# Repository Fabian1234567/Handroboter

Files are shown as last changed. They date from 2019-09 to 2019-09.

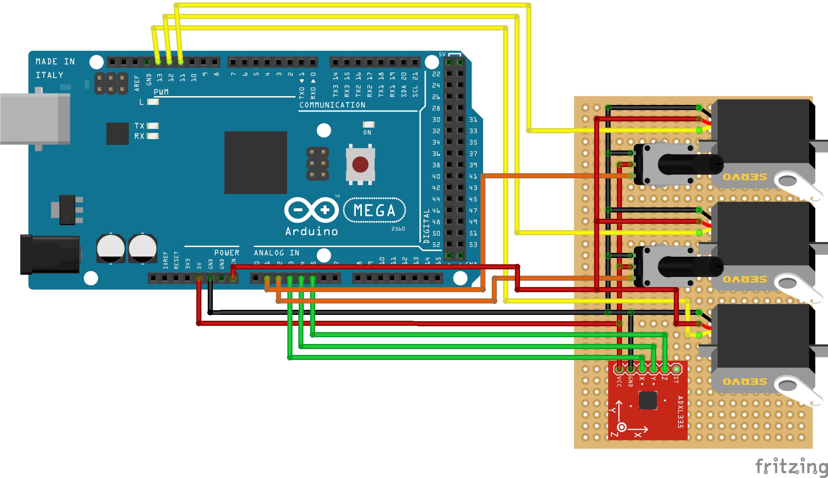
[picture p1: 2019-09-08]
Konstruktionen/BauplanRoboter_Schaltplan.jpg

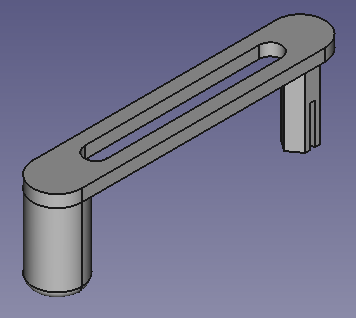
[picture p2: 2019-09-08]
Konstruktionen/Poti.png

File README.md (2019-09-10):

# Handroboter

SIA (Schüler-Ingenieurs-Akademie) ist ein Schulfach in Baden-Würrtemberg, wo man Roboter und andere Maschinen mit Microkontroller baut. Das Fach wird in der 11. Klasse an einzelnen Schulen angeboten und kann als mündliches Abitur gezählt werden. 

Mein Projektziel:  Bau eines Roboterarms, dessen Steuerung durch die menschlichen Hand-Bewegungen mittels eines mit Sensoren versehenen Handschuhs erfolgt. Die Sensorsignale werden von einem Mikrocomputer (Arduino) verarbeitet, der damit die Stellmotoren des Roboterarmes steuert. Wenn möglich soll der Roboterarm gezielt kleine Gegenstände bewegen und heben können.
- Das Projektziel wurde erreicht.

Normalerweise arbeitet man in Teams, doch mich hat man aufgrund meines Vorwissens in eine Einzelgruppe gesetzt. Als Microkontroller haben wir Arduino Megas genutzt. Meine Dokumentation, Werkstatttagbeücher, Konstruktion, Präsentation und Programm findet man hier. Vielleicht hilft es euch, ein ähnliches Projekt umzusetzen :) .

Meine Noten im Fach: 
- Gesamtbewertung: 14p
- incl. Jahresleistung: 14p
- u. Dokumentation: 11p
- u. Kolloquien: 15p

Ich wünsche euch viel Spaß mit diesem Projekt!
- If you have any questions please contact me at fabian.exel@gmx.de -

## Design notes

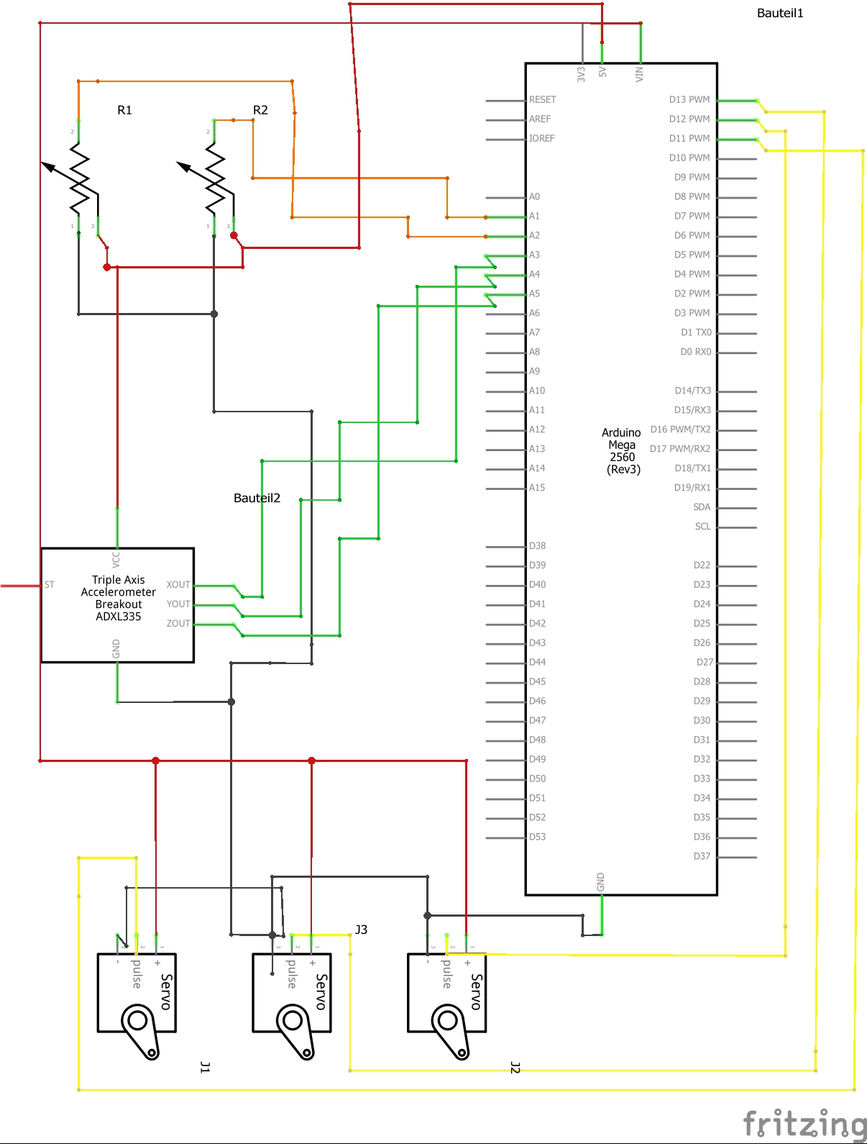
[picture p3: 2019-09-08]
Konstruktionen/BauplanRoboter_Steckplatine.jpg

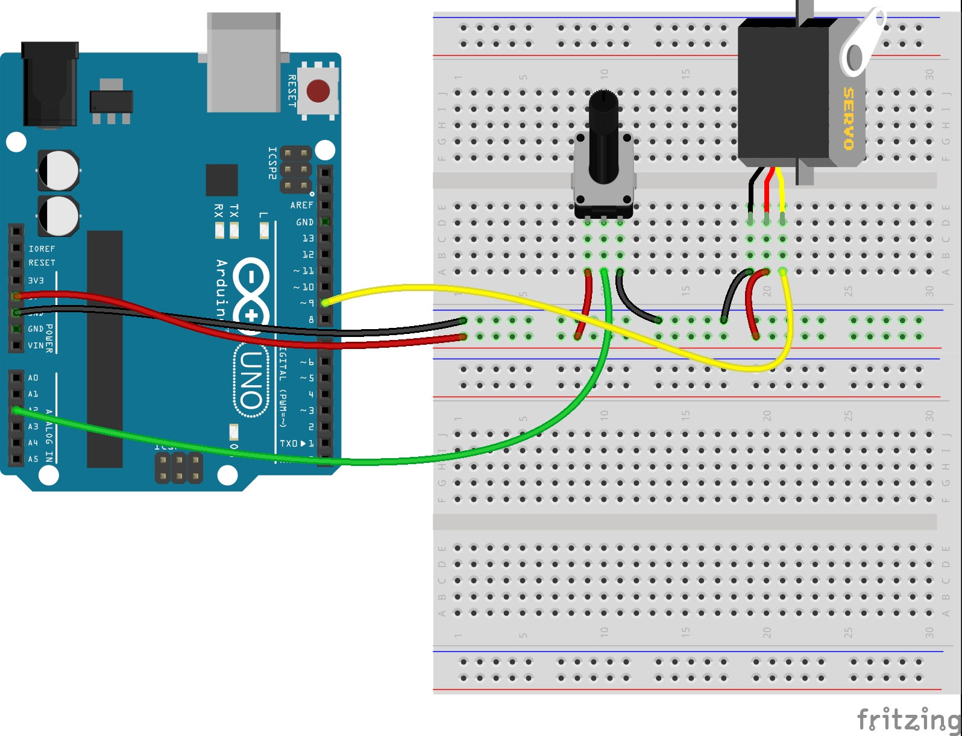
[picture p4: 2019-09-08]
Konstruktionen/AnalogInputToServo_Steckplatine.jpg

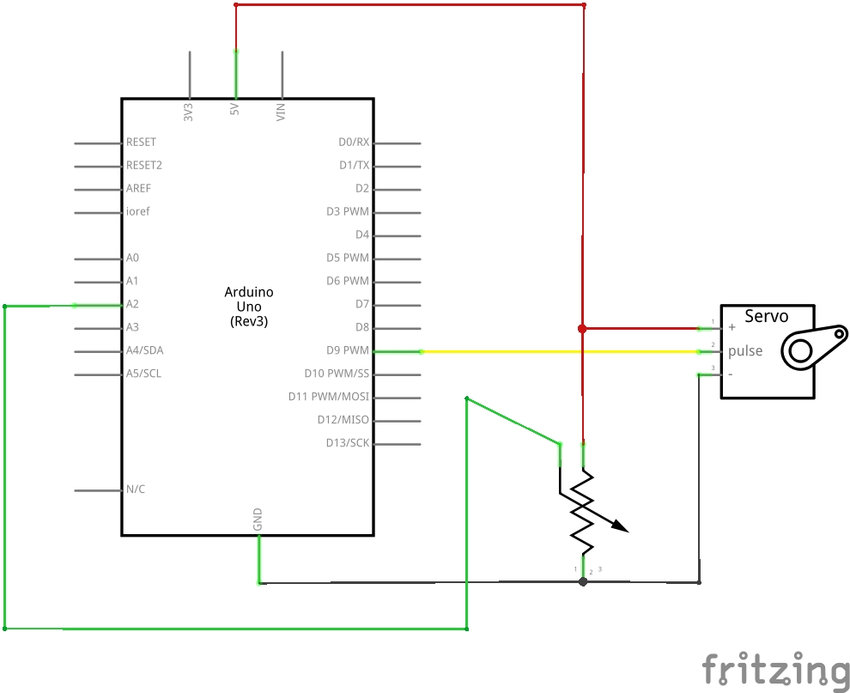
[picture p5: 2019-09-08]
Konstruktionen/AnalogInputToServo_Schaltplan.jpg

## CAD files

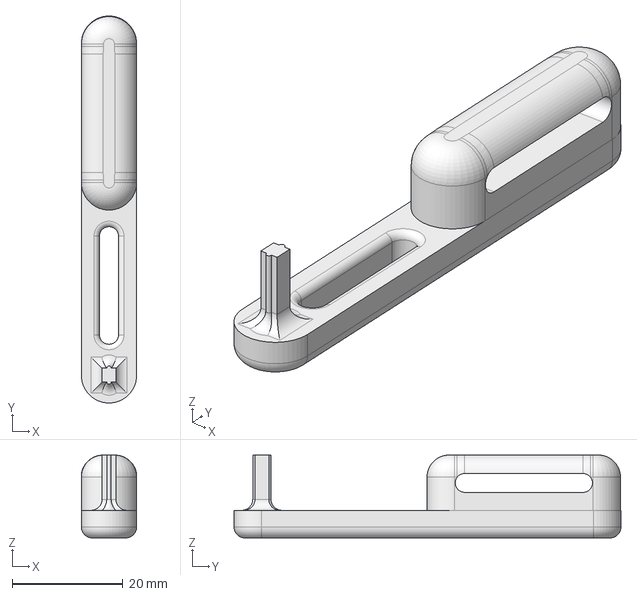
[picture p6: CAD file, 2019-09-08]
Konstruktionen/Poti2KurzÜberarbeitet.FCStd
10.0 x 70.0 x 15.0 mm

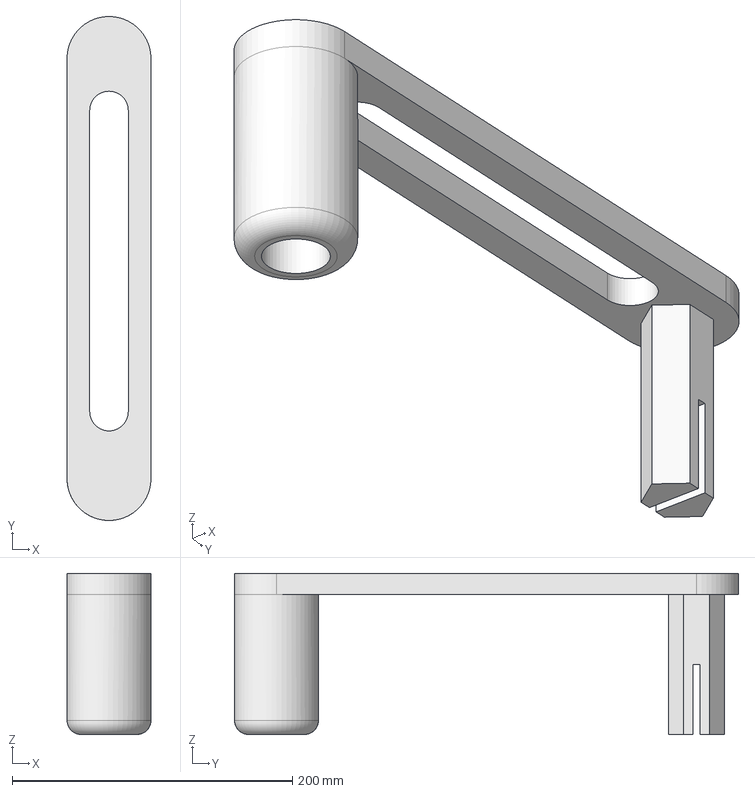
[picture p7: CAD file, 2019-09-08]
Konstruktionen/Poti.fcstd
60.0 x 360.0 x 115.0 mm

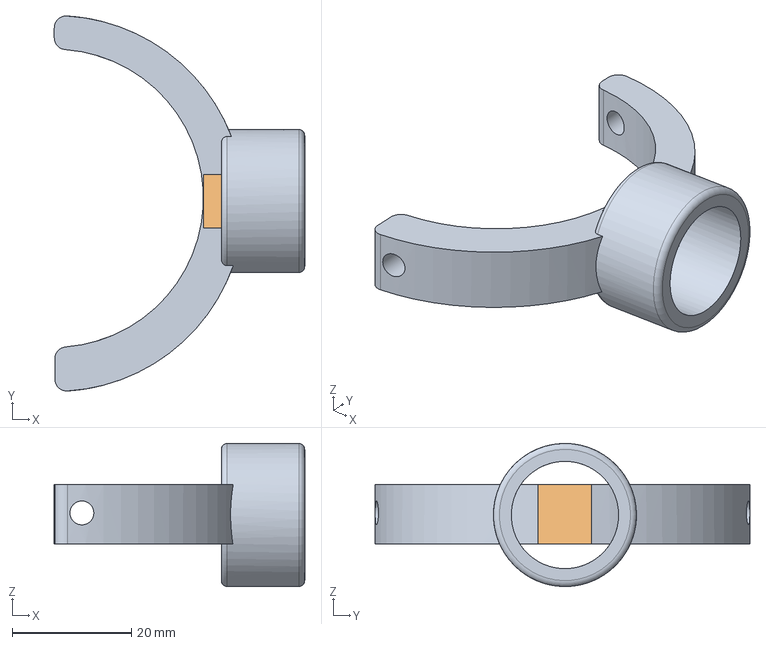
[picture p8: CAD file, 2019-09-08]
Konstruktionen/Hand.FCStd
42.0 x 62.9 x 24.0 mm
Würfel001

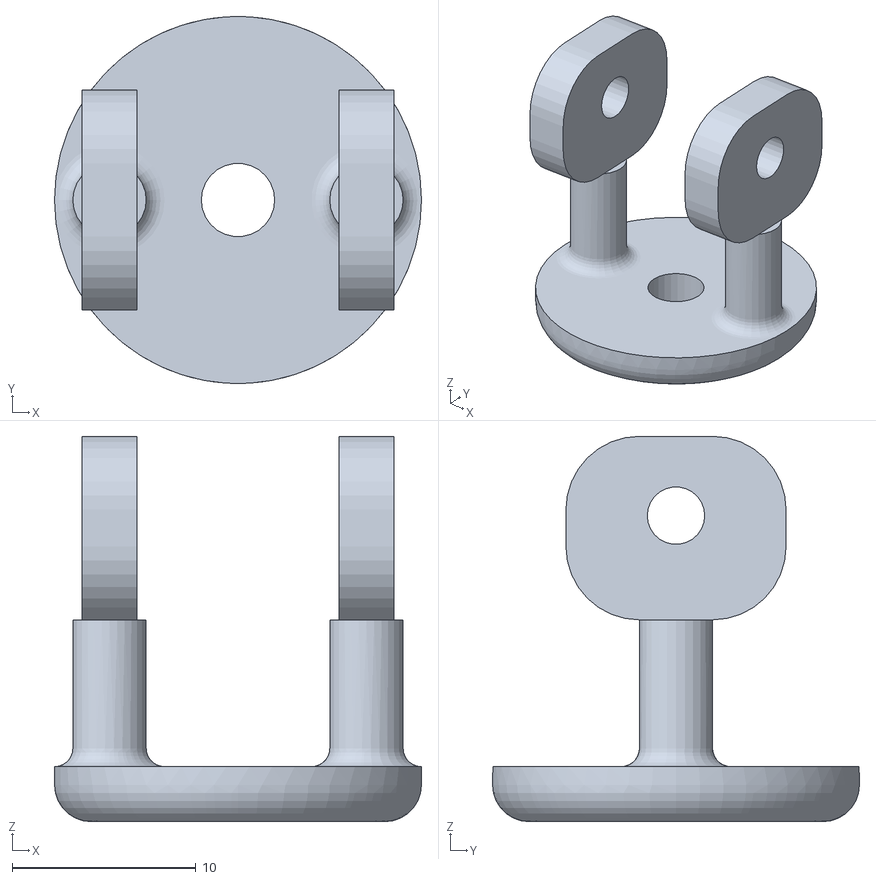
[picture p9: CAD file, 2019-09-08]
Konstruktionen/Poti-Hand-Dreh.stl
20.0 x 20.0 x 21.0

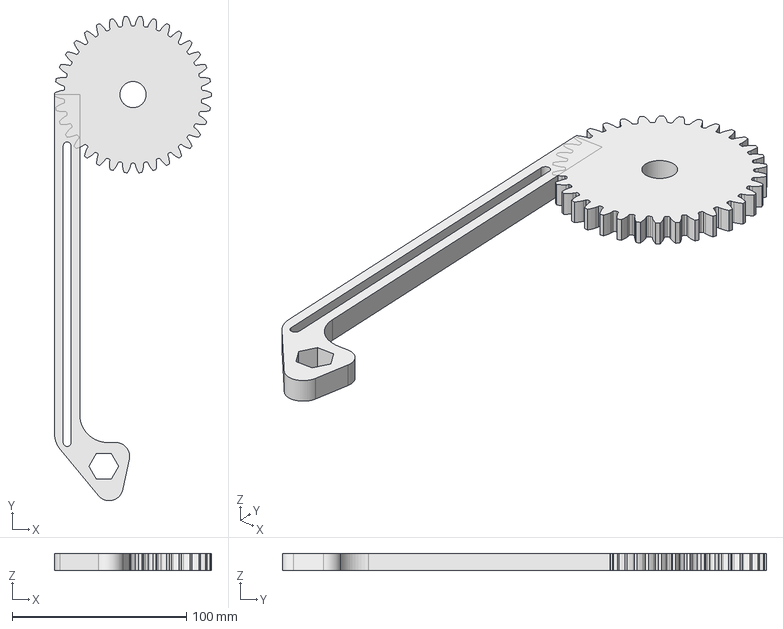
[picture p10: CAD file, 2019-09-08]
Konstruktionen/ZahnradGreifer.FCStd
90.0 x 277.8 x 10.0 mm

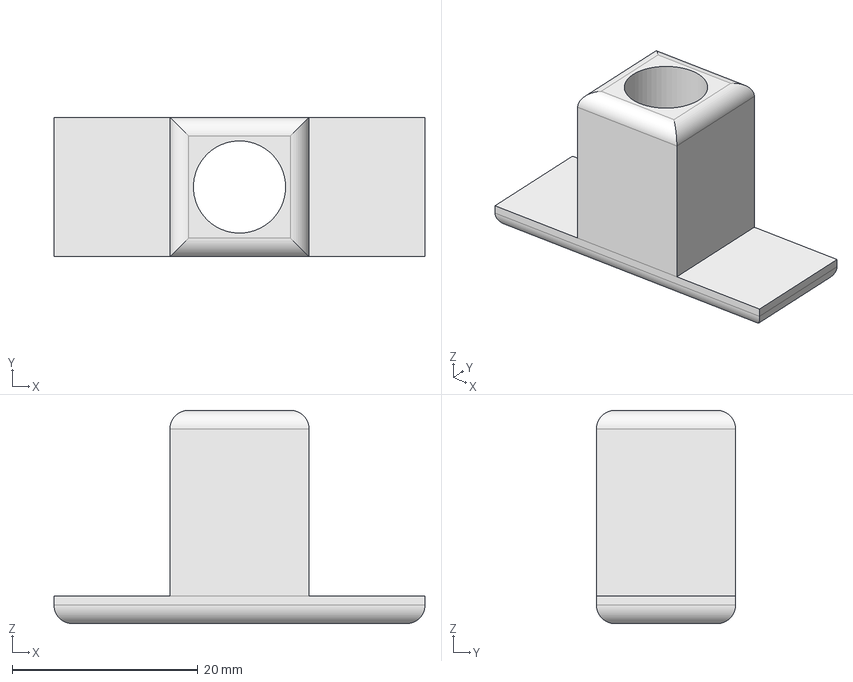
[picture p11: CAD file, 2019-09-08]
Konstruktionen/Stift.FCStd
40.0 x 15.0 x 23.0 mm

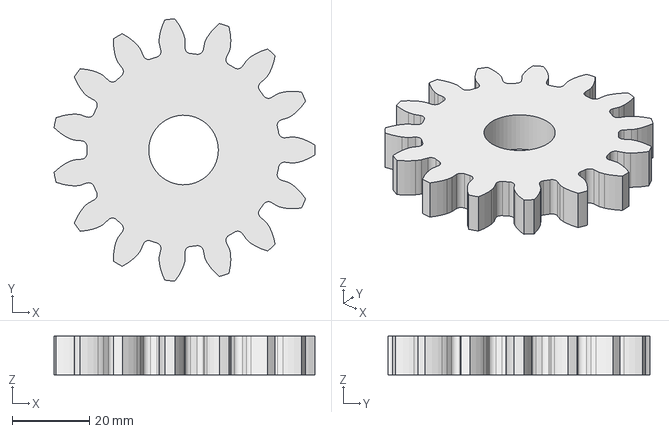
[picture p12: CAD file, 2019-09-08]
Konstruktionen/ZahnradAmServo.FCStd
67.5 x 67.9 x 10.0 mm

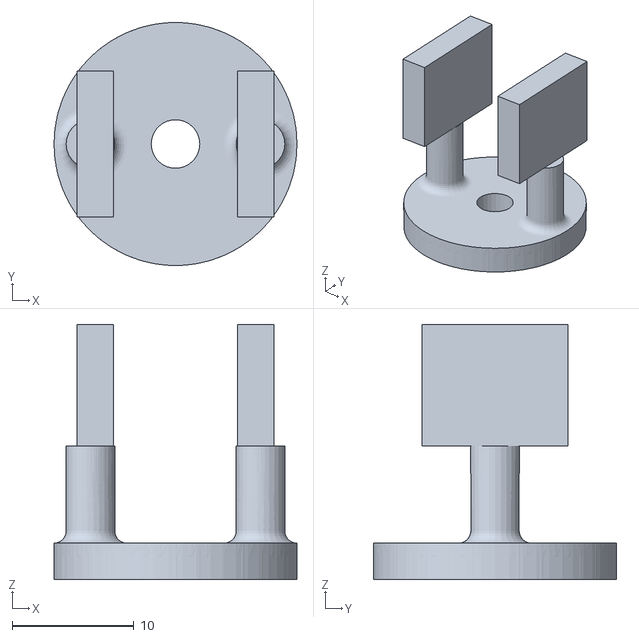
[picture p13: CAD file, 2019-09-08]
Konstruktionen/DrehTeil.stl
20.0 x 20.0 x 21.0

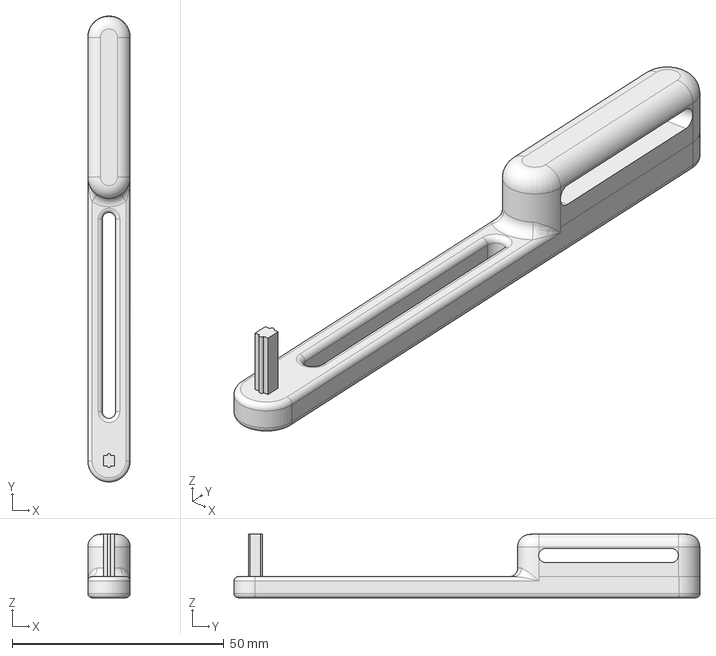
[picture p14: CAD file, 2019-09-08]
Konstruktionen/Poti2.FCStd
10.0 x 110.0 x 15.0 mm

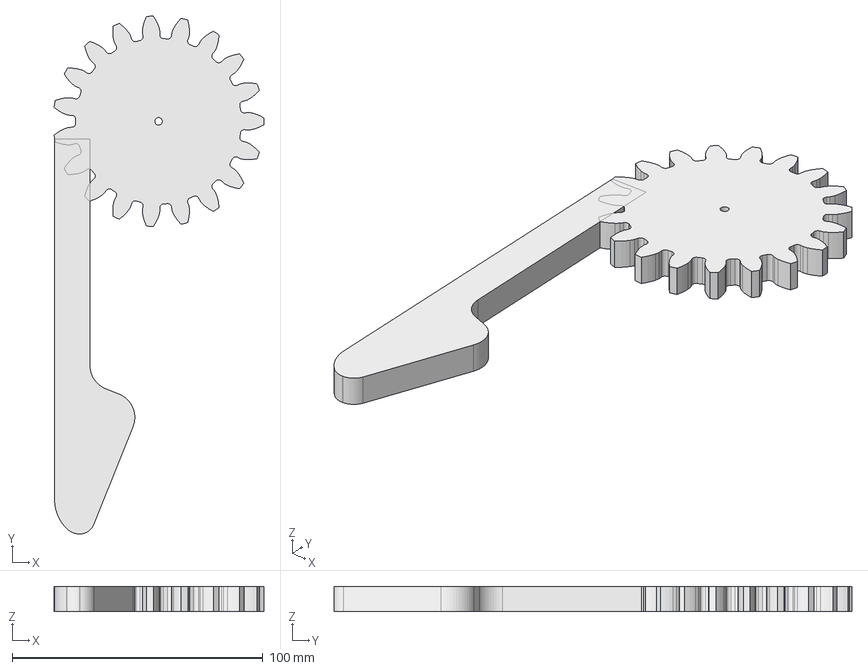
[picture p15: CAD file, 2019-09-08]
Konstruktionen/ZahnradGreifer2.FCStd
83.6 x 206.4 x 10.0 mm

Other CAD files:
Konstruktionen/Poti2Kurz.FCStd
Konstruktionen/Poti-Handschuh.stl
Konstruktionen/richtigesDrehteil.stl
Konstruktionen/Dreh.FCStd
Konstruktionen/Hand.stl
Konstruktionen/Poti2.stl
Konstruktionen/Poti2Kurz.stl
Konstruktionen/Poti2KurzÜberarbeitet.stl
Konstruktionen/Stift.stl
Konstruktionen/ZahnradAmServo.stl
Konstruktionen/ZahnradGreifer.stl

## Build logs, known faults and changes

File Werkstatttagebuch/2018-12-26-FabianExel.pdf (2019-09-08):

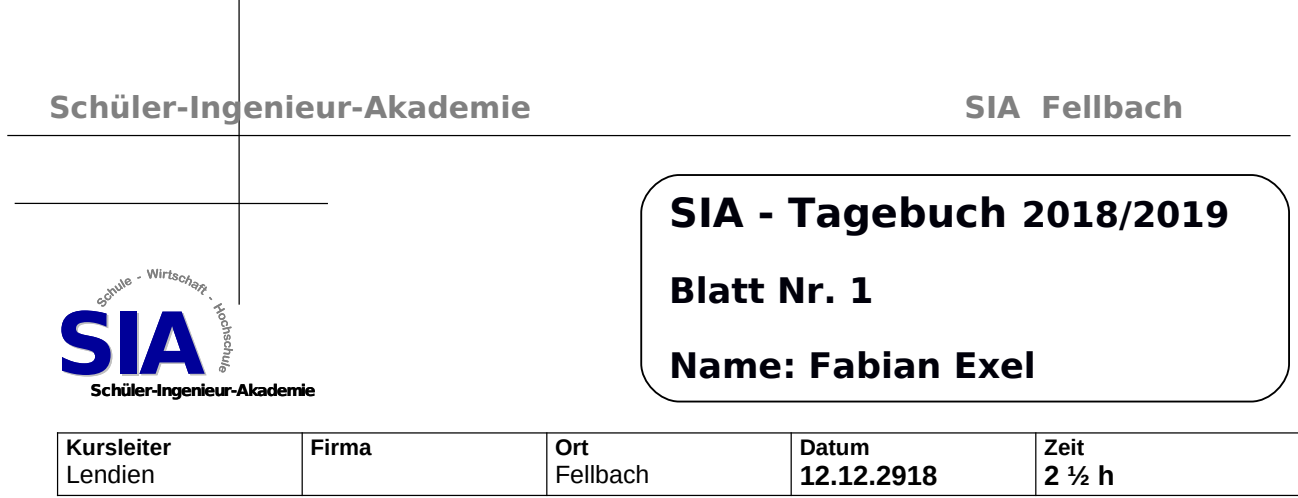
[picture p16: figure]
Schüler-Ingenieur-Akademie; SIA Fellbach; SIA; Schüler Schüler-Ingenieur Ingenieur-Akademie Akademie; Kursleiter Lendien; Firma; Ort; Fellbach; Datum 12.12.2918; Zeit 2 ½ h; SIA - Tagebuch 2018/2019; Blatt Nr. 1; Name: Fabian Exel

### Thema

## Programmierung von Sensor + Motoren Konstruktion

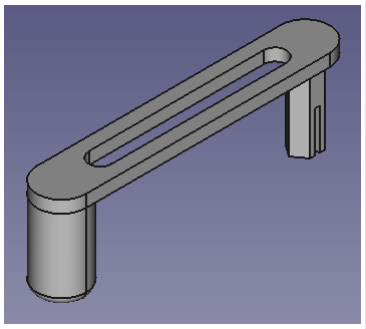
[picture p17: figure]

Was wurde gemacht?

Es wurde für die Hand ein Verbindungsstück zischen einem Potentiometer und dem Finger konstruiert. Man braucht dieses Verbindungsstück, damit man Werte mit dem Potentiometer aufnehmen kann. Als anderen Sensor könnte man noch Neigungssensoren nutzen, nur dann würde es mit der Programmierung und dem Kabelsalat viel schwieriger werden, weil man die Neigungssensoren untereinander abstimmen muss (wenn man mehrere nutzt) und man pro Neigungssensor 5 Kabel hat anstatt 3 Kabel wie bei einen Potentiometer. Das Verbindungsstück muss mindestens zwei mal ausgedruckt werden, weil 2 Potentiometer eingebaut werden sollen (siehe Tagebucheinträge von davor). Später wurde noch mit dem Arduino-Programm angefangen (siehe Seiten danach). Mir ist es dabei wichtig gewesen, dass der Arduino alle seine Werte in einer Seriellen Konsole anzeigt, damit ich weiß, wie ich die Werte verändern muss, damit der Roboter keine komischen Bewegungen macht. Eventuell werden noch ein paar Befehle programmiert, womit man das Programm auch laufend modifizieren kann. Ganz wichtig ist aber die Hand zu testen, bevor sie mit dem Roboter verbunden wird. Dies kann durch eine Simulation zum Beispiel geschehen. Eine andere Sache, die ich auch sehr wichtig finde, ist die Frage, was passiert wenn man seine (echte) Hand in einer Bewegung bewegt, wo sich der Neigungssensor auf einer bestimmten Achse nicht bewegen soll.
In der Regel wird er veränderte Werte aufnehmen, weil die
wenigsten Menschen es schaffen werden, ihre Hand so perfekt zu

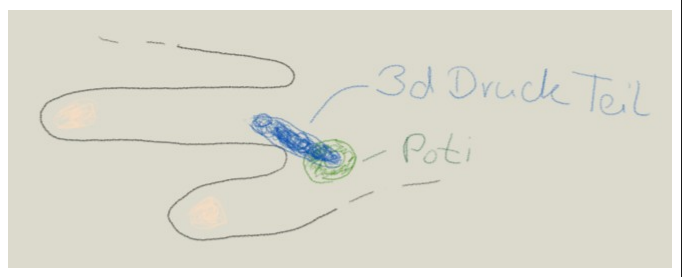
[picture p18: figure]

bewegen, dass kein veränderter Wert auf dieser Achse zu messen ist. Um dieses Problem zu umgehen habe ich eine gewisse Toleranz mit rein programmiert, damit so etwas nicht passiert.

Was wir nächste Stunde voraussichtlich geschehen?

Der Roboterarm wird angefangen zu bauen, die Bauteile sind ja schon alle vorhanden. Die Holzplatte mit dem Ständer werden bei mir Zuhause schon vorgefertigt, damit ich mich nächster Stunde damit nicht aufhalten muss. Des weiteren wird noch Pappelholz mitgenommen zur Weiterverarbeitung beim Roboterarm.

Arbeitsblätter:

Schaubild 1: Verbindungsstück zwischen Potentiometer und Finger

Schaubild 2: Wie das Verbindungsstück eingebaut werden

Arduino Sketch Version 1

#include <Servo.h>

int accZPin=0;
int accYPin=1;
int accXPin=2;
int onePot=3;
int twoPot=4;

int eins;
int zwei;
int drei;

int start;
int abweichung=30;
int neu;

Servo first;
Servo second;
Servo third;

void setup() {
// put your setup code here, to run once: Serial.begin(9600);
first.attach(10);
second.attach(11);
third.attach(12);
start=analogRead(accZPin);
}

void loop() {
// put your main code here, to run repeatedly: Serial.print(" X=");
Serial.print(analogRead(accXPin)); Serial.print(" Y=");
Serial.print(analogRead(accYPin)); Serial.print(" Z=");
Serial.println(analogRead(accZPin)); eins = analogRead(onePot);
eins = map(eins, 0, 1023, 30, 300); Serial.print(" Potentiometer 1: "); Serial.print(onePot);
zwei = analogRead(twoPot);
zwei = map(zwei, 0, 1023, 30, 300); Serial.print(" Potentiometer 2: "); Serial.println(twoPot);
first.write(eins);
Serial.print(" Servo 1: "); Serial.print(eins);
second.write(zwei);
Serial.print(" Servo 2: "); Serial.println(zwei);
if(analogRead(accZPin)>start+abweichung){ neu=analogRead(accZPin)+start; start=neu;
drei=map(drei, 0, 1023, 20, 310); third.write(drei);

}

if(analogRead(accZPin)<start-abweichung){ neu=analogRead(accZPin)-start; start=neu;
drei=map(neu, 0, 1023, 20, 310); third.write(drei);
}
Serial.print(" start-Wert für Neigungssensor: "); Serial.print(start);
Serial.print(" Neuer Wert: "); Serial.print(neu);
Serial.print(" Servo 3: "); Serial.println(drei);
}

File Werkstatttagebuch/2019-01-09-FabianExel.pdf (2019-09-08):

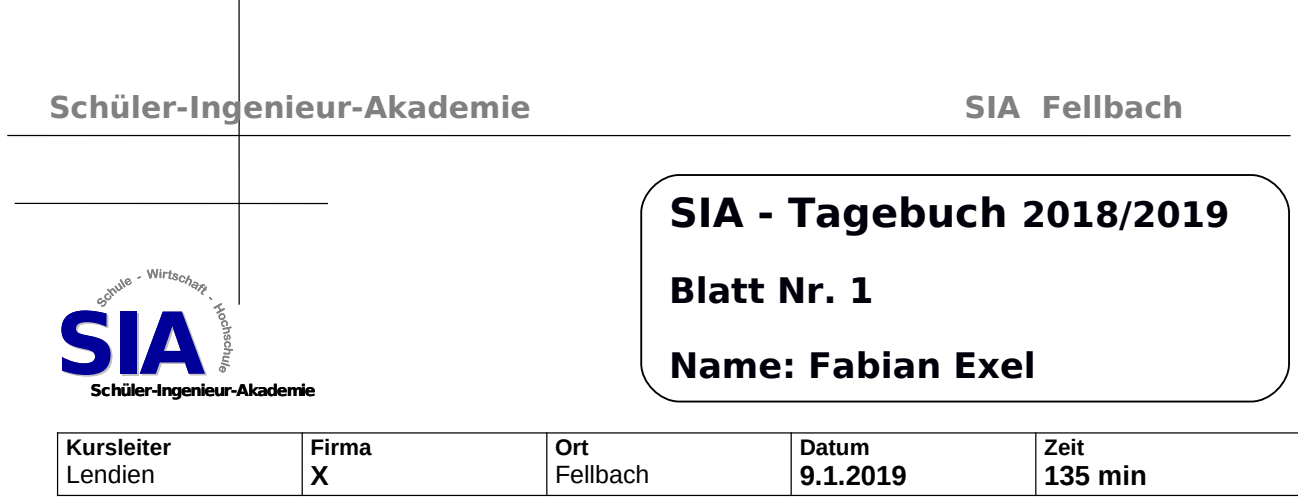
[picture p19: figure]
Schüler-Ingenieur-Akademie; SIA Fellbach; SIA; Schüler Schüler-Ingenieur Ingenieur-Akademie Akademie; Kursleiter Lendien; Firma X; Ort Fellbach; Datum 9.1.2019; Zeit 135 min; SIA - Tagebuch 2018/2019; Blatt Nr. 1; Name: Fabian Exel

### Thema

## Anfang vom Bau des Roboters

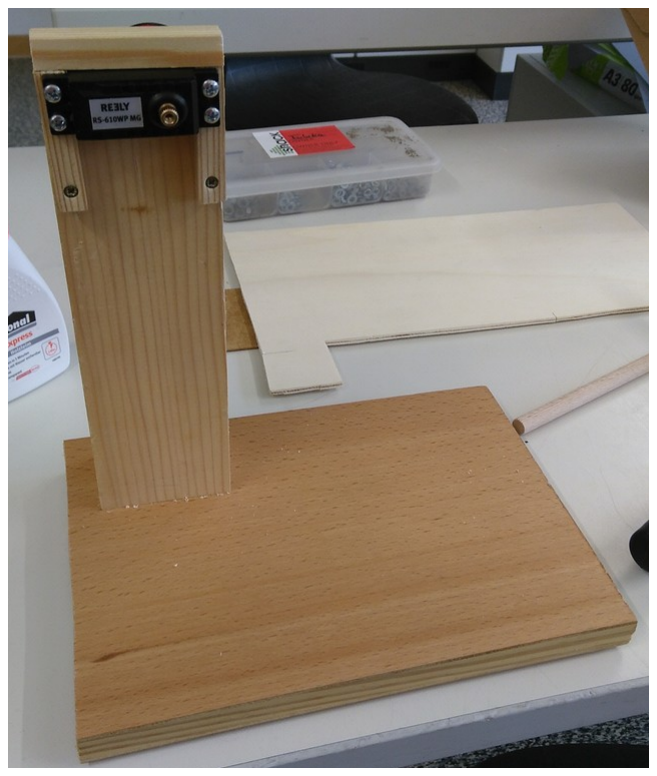
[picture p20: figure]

Was wurde gemacht?
Wie angekündigt wurde schon die Grundplatte mit der Säule bei mir Zuhause vorgefertigt, um Zeit zu sparen. Heute konnte somit direkt mit der Montage der Servos begonnen werden. Mir war wichtig, dass der am stärksten belastete Servo auch der stärkste ist, damit dieser nicht direkt aufgrund zu hoher Kraft in die Knie geht. Außerdem wurde der erste Servo direkt mit 4 Schrauben (2 je Seite – siehe Bild) montiert, damit dieser auch stabil an seinem Platz bleibt und nicht sich losbricht durch äußere Krafteinwirkung.
Später wurde noch der 2. Servo montiert. Dies stellte anfangs eine gewisse Schwierigkeit da, weil es noch unklar war, wie man ihn an den 1. Servo überhaupt montiert. Die erste Idee war, dass man ein Holzstück nimmt, ein großes Loch bohrt und dieses dann auf den Servoanschluss drüber steckt. Dies hat nicht funktioniert, da dieses Holzstück nie fest genug am Servo war und sich andauernd gelöst hat. Zum Glück ist mir aber dann ein Gewinde an dem Servoanschluss, welches auch rein zufällig M3 war – genauso wie meine Schrauben. Damit war klar, dass man für eine stabile Verbindung einfach ein Stück Holz mit der Schraube richtig fest schrauben muss – was ich auch gemacht habe.
Das einzige Problem, was sich jetzt dann aufgetan hat, war, dass mir die Verbindung zu sehr herum waberte, zu viel Spiel dem Roboterarm gibt. Doch das ist aufgrund der Zeit eventuell ein Problem der nächsten Stunden. Dieses Problem muss auch nicht sofort gelöst werden, da bei mir alles mit Schrauben verbunden wurden ist. Das war Absicht, aus dem einfachem Grund, dass man jedes Teil schnell austauschen kann, falls es kaputt geht oder es ein besseres gibt. Außerdem kann man den Roboter und seine Materialien später leichter recyclen, wenn ein anderes Projekt die Teile gerade braucht (Umweltaspekt).
Was wird in der nächsten Stunde voraussichtlich geschehen?
Der Plan ist, dass der Roboterarm dann größtenteils fertig wird. Das heißt den letzten Servo verbauen und Kabel verlegen. Nur der Greifer muss aufgrund des fehlenden 3D-Druckers warten, weil dieser 3 Zahnräder für den Arm drucken soll. Eventuell wird auch die Stelle mit dem zu großem Spiel ausgetauscht, aber nur, wenn genügend Zeit noch vorhanden ist, da es wichtiger ist, einen ganzen Roboterarm mit Spiel zu haben anstatt einen halben Roboterarm ohne Spiel. Abschließend kann ich aber sagen, dass es mit dem Roboter wie geplant voran geht und auch der Zeitplan eingehalten wird.

Arbeitsblätter: X

Schaubild 1: An die Grundplatte wurde wie im CAD-Modell schon die Säule mit dem 1. Servo montiert.

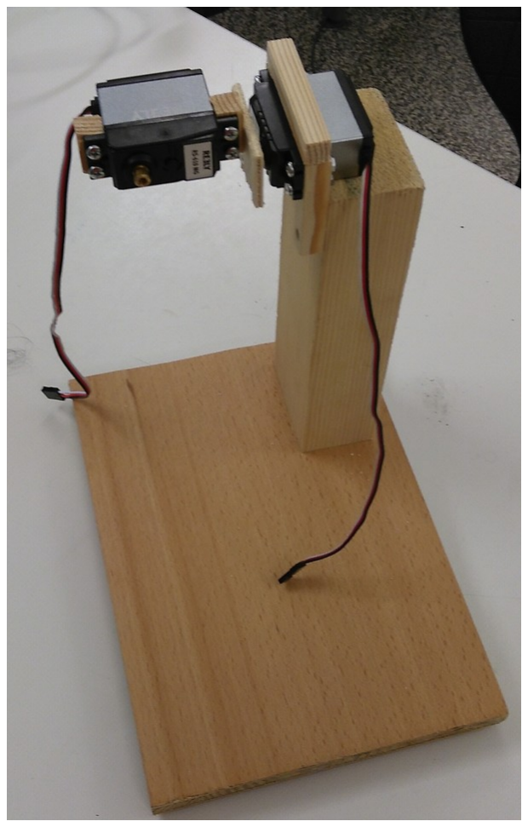
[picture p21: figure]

Schaubild 2: Der 2. Servo am ersten Servo montiert

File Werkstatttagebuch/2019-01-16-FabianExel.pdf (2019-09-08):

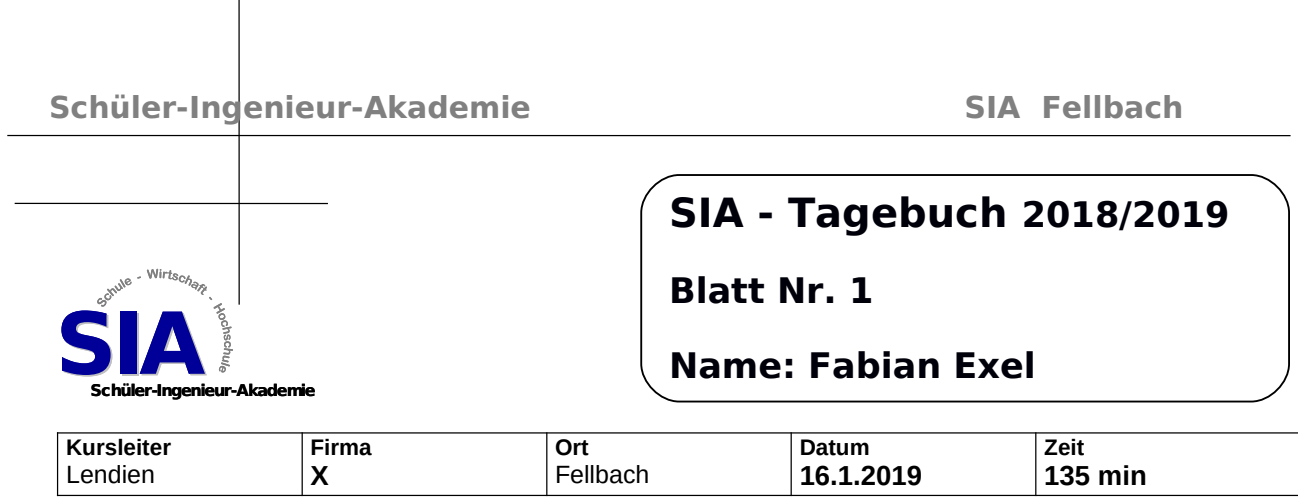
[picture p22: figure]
Schüler-Ingenieur-Akademie; SIA Fellbach; SIA; Schüler Schüler-Ingenieur Ingenieur-Akademie Akademie; Kursleiter Lendien; Firma X; Ort Fellbach; Datum 16.1.2019; Zeit 135 min; SIA - Tagebuch 2018/2019; Blatt Nr. 1; Name: Fabian Exel

### Thema

## Roboterarm ist fast fertig

Was wurde gemacht?

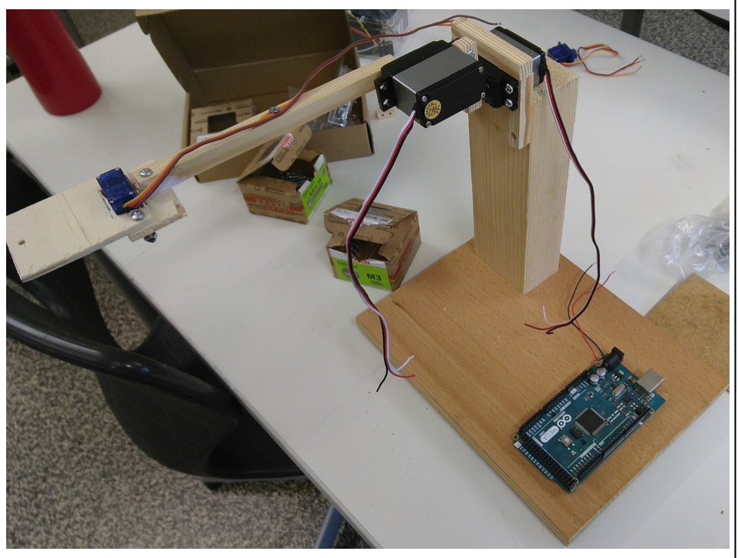
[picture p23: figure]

Es wurde im Grunde am Roboterarm weiter gebaut. Es fehlte nur noch ein Servo, der nur noch montiert werden muss. Der komplette Greifer wird aber auf sich warten müssen wie schon im letzten Tagebucheintrag erwähnt wurde aufgrund fehlendem 3D Druckers.

Damit der Arm eine weitere Distanz erreichen kann, wurde zwischen dem mittleren- und dem Greifer- Servo eine etwas längere (~ 15 cm lang – fast bis zum Boden reichende) Stange eingebaut. Je nach dem wie der erste Servo an der Säule gestellt ist, kann ich nach oben oder
unten | beziehungsweise | nach | rechts | oder | links
schwenken. Die Stange an sich wurde mit einer Schraube am mittleren Servo montiert, genau so wie es mit der
ersten Servoverbindung es auch schon gemacht wurden
ist (siehe letzten Tagebucheintrag).

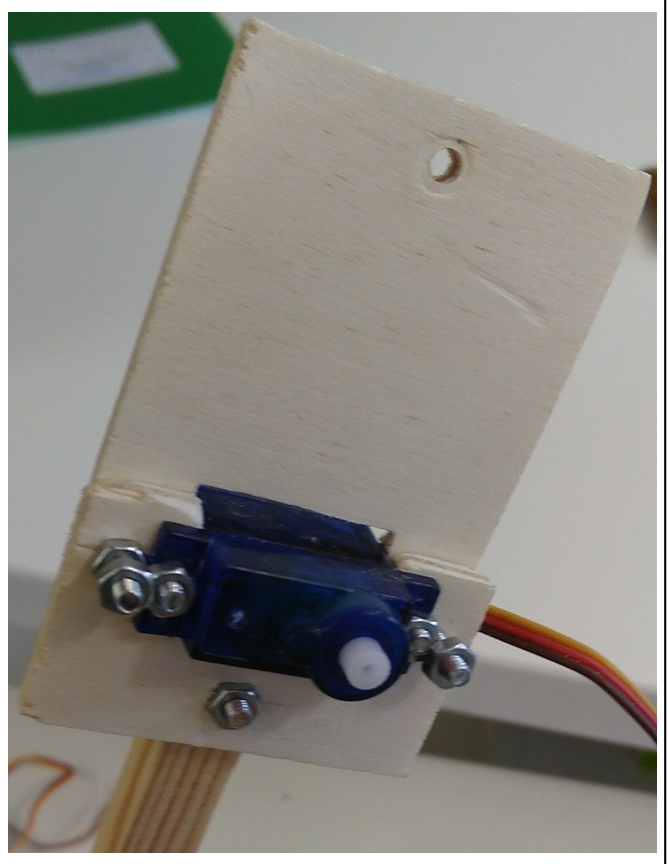
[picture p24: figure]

Am anderen Ende der Stange musste nun nur noch der Servo so montiert werden, dass man später noch die Zahnräder passend einbauen kann. Der Servo soll außerdem ein leichter sein (die Zahnräder müssen aus selben Grund auch leicht sein), da die anderen beiden Servos über die Hebelkraft schon mehr tragen müssen. Des weiteren muss der kleine Servo auch nicht so große Kräfte bewegen, wie die anderen Servos, da, wie im Projektziel beschrieben, das Tragen eines Stückes Papier schon ausreicht. Nur die Montage des Servos wurde äußerst schwierig, weil man irgendetwas braucht, um hinterher die Zahnräder, welche von den einem Servo gesteuert werden sollen, zu verbinden. Am besten eignete sich dafür eine Platte, wo man schlicht Löcher bohrt für die Achsen der Zahnräder. Jetzt war die Frage: Wie bekommt man den Servo an/in die Platte? Ein rechteckiges Loch in eine Holzplatte sägen ist mit dem verfügbaren Werkzeug recht schwierig. Als Lösung habe ich zwei Platten ausgesägt mit dem Sinn, dass zwischen den beiden Platten der Servo steckt (außerdem hat eine Platte auch eine extra Einkerbung für den Servo bekommen, damit der Servo stabiler eingebaut ist). Der Servo steckte jetzt drin, hat aber aufgrund seiner kleineren Größe nur zwei Einkerbungen (nicht Löcher!) für Schrauben, was das ganze noch etwas instabil machte. Gelöst wurde das durch längere Schrauben von der gesamten Holzplatte (also die Schrauben, die die beiden Holzplatte um
den Servo verbinden). Die haben dann gegen gedrückt und durch je eine
weitere Mutter dafür gesorgt, dass ganze Gebilde stabil hält. Man kann
noch hinzufügen, dass das Platten-Servo-Konstrukt durch eine Schraube an die Stange montiert wurden ist.

Arbeitsblätter: X

Schaubild 1: Der Roboterarm am Ende der Mittwochsstunde

Schaubild 2: Montage des Servos: Überhängendes Holzbrett für die Zahnräder; eine Schraube an die Stange; die spezielle Verbindung Servo - Holzbrett

Schüler-Ingenieur-Akademie | SIA Fellbach

Dies hat den Vorteil, dass man das Konstrukt schnell demontieren kann (z.B.: wenn man die Zahnräder hinzufügen möchte; etwas kaputt geht) und dass man das Konstrukt bei bedarf auch drehen kann, falls irgendetwas diese Aktion hervor ruft (noch ist unklar, welche Aktion es sein könnte - aber es kann immer sein, dass etwas nicht passt).

Als der letzte Servo montiert war, wurde nur noch angefangen, die Kabel so zu verlegen, dass nicht ein Verheddern des Armes im Kabelsalat passieren kann. Der Arduino wurde bei der Gelegenheit auch noch schnell an die Platte mit 4 Schrauben montiert, damit man die Kabel gleich zum Endpunkt passend verlegen kann.

Als letzten Punkt wurde noch schnell die Aufhängung zwischen dem mittleren- und dem Säulen- Servo ausgetauscht. Wie im letzten Tagebucheintrag beschrieben, war die alte Aufhängung sehr wackelig, zum anderen ist heute dazu noch durch die Stange aufgefallen, dass der Arm vor allem durch diese Aufhängung ziemlich schräg steht. Innerhalb von 10 min wurde dann die komplette Aufhängung ausgetauscht, was mit der Schraubenverbindung so schnell ging. Bei der alten Verbindung gab es eine Pappelholzplatte, verbunden mit einer Stange. Die Pappelholzplatte sorgte aufgrund ihrer leichten Flexibilität für das Spiel und die Verbindung für eine solche Schrägstellung. Da Holz weicher ist als andere Materialien kann es dort immer vorkommen, dass es Schrägstellungen gibt, dafür kann man aber Holz leichter verarbeiten als andere Materialien, es ist auch leichter als andere Materialien und die Flexibilität des Holzes kann für die Stabilität auch von Vorteil sein, weshalb ich mich am Ende für Holz als Baumaterial entschieden habe. Die neue Verbindung besteht jetzt nur noch aus einem Stück Holz, womit ich mir zum einem eine extra Verbindung zwischen Holzbretter spare und zum anderem eine stabilere Verbindung habe als das Pappelholz. Zusammenfassend kann ich sagen, dass sich der Eingriff gelohnt hat, weil die Schräge wie auch das vorherige Spiel weggegangen ist.

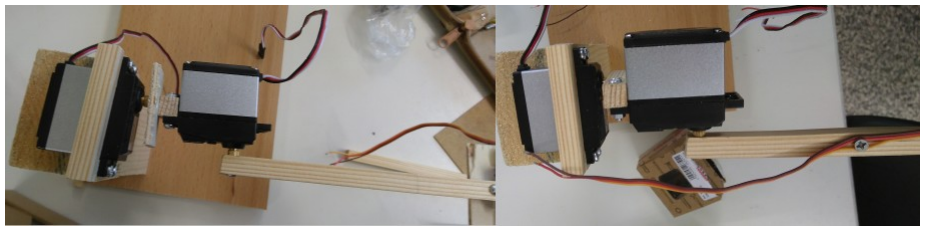
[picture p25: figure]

Was wird in der nächsten Stunde voraussichtlich geschehen?
Da die 3D-Druck Teile immer noch fehlen, wird am Roboterarm nicht mehr weiter gebaut. Es werden maximal die letzten Kabel verlegt, um oben beschriebenes verheddern zu verhindern. Es wird eher mit dem Bau des Handschuhs angefangen. Da kommt dann zuerst der Neigungssensor – weil auch bei den Potentiometern je ein kleines 3D Druckteil fehlt. Der Zeitplan sieht aber für mich sehr gut aus, weil ich noch eine Dreifachstunde für den Roboterarm übrig habe laut Plan – Zeit, die ich nicht komplett benötige und für andere Sachen nutzen kann.

Schaubild 3: Vergleich bei der Biegung: links die alte Verbindung; rechts die neue Verbindung

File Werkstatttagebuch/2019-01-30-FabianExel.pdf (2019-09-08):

Schüler-Ingenieur-Akademie; SIA Fellbach; SIA; Schüler Schüler-Ingenieur Ingenieur-Akademie Akademie; Kursleiter Lendien; Firma X; Ort Fellbach; Datum 16.1.2019; Zeit 135 min; SIA - Tagebuch 2018/2019; Blatt Nr. 1; Name: Fabian Exel

### Thema

## (Fast) Fertigstellung des Roboters + Ausflug in andere Techniken

Was wurde gemach?
Es wurde die Verkabelung des Roboters fertig gemacht. Das
einzige was jetzt noch beim Roboter fehlt, sind die 3D-Druck
Teile.

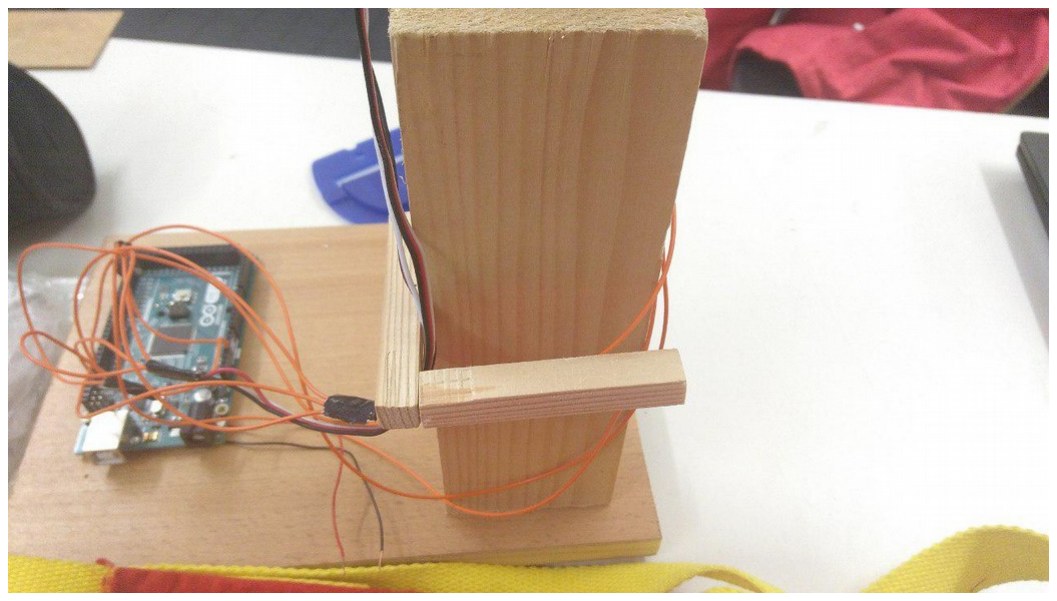
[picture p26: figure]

Einen Schaltplan über die Verkabelung gibt es auch schon. Da es recht wenig Kabel gibt, wurde auch drauf geachtet, dass alles so gesteckt wird, dass man den Roboter auch von einem Arduino UNO Layout aus Steuern kann, ohne das Programm vorher verändern zu müssen. Um das möglich zu machen darf man aber nur die Digitalen Pins von 0-13 wie auch die Analogen Pins von 0-5 nutzen. Der spätere Vorteil wird sein, dass man leichter den Computer austauschen kann falls es nötig wird (zum Beispiel wenn die Schule den Arduino Mega wieder zurück haben möchte).

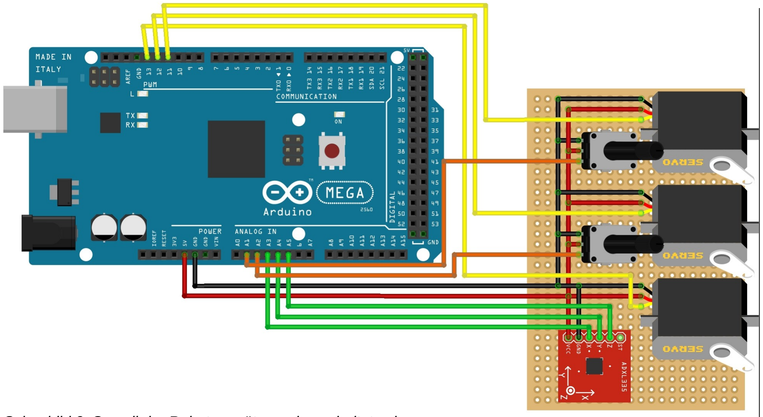
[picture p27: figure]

Arbeitsblätter: Handroboter: https://homes.cs.washington.edu/~todorov/papers/KumarICRA13.pdf Ausdehnung Kabel: http://www.schule-bw.de/faecher-und-schularten/mathematischnaturwissenschaftliche-faecher/physik/unterrichtsmaterialien/waermelehre/ausdehnung/ausdehnung_festkoerper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 (http://www.schule-bw.de/faecher-und-schularten/mathematisch-naturwissenschaftliche-faecher/physik/unterrichtsmaterialien/waermelehre/ausdehnung/ausdehnung_fes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)

Schaubild 1: Die Verkabelung am Roboter mit dem zusätzlichem „Arm“

Schaubild 2: So soll der Roboter später mal geschaltet sein

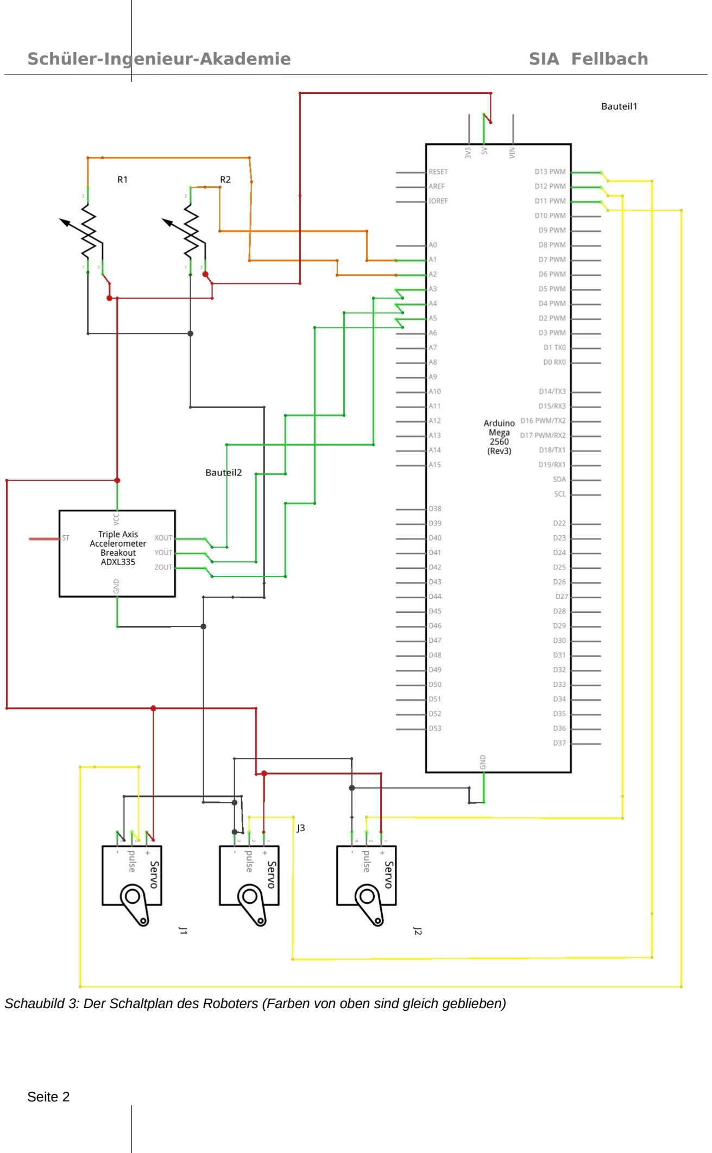
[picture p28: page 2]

Schaubild 3: Der Schaltplan des Roboters (Farben von oben sind gleich geblieben)

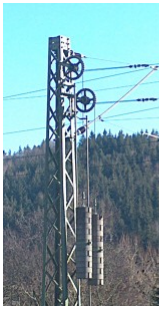
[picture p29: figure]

Bei der Verkabelung wurde, wie das letzte mal schon beschrieben, darauf geachtet, dass sich die Kabel nicht verheddern. Heute habe ich einen kleinen Arm extra dran gebaut, damit das verheddern nicht passieren kann. Die Kabel sind hierbei in einer kleiner Führung aus zwei kleinen Hölzer, wo sie von alleine nicht rauskommen können, sich aber noch etwas bewegen können. Das ist wichtig, damit wenn der Roboter sich mal bewegt, kein Kabel mit reist, welches zum Beispiel am Servo ganz vorne am Greifer dran ist. Im Prinzip müsste man sogar ein Gewicht dran machen, um das Kabel an einem Punkt nach unten zu ziehen, damit das Kabel zum einem nicht durchhängen kann und sich dadurch verheddern kann, zum anderen sich immer noch bewegen kann, falls sich der Arm zum Beispiel „streckt“. Das Prinzip wurde schon bei Oberleitungen bei Zügen verwendet, wo das Kabel auch immer gespannt sein muss, da es sonst reisen könnte. Da bewegt sich das Kabel aber nur, weil im Sommer das Kabel durch die Wärme länger wird, weil die Atome des Kabels mehr Platz benötigen. Ob das Gewicht noch nötig wird, wird sich in nächster Zeit noch zeigen. Vorerst wird aber kein Gewicht eingebaut, solange es auch nicht gebraucht wird.

Am Ende wurde noch das erste Zahnrad für den Greifer konstruiert. Dessen Aufgabe wird es sein, die Kraft vom Servo auf die beiden „Finger“ des Greifers zu übertragen. Um zur Servoachse passen zu können ist das mittlere Loch größer als bei den anderen Zahnräder. Des weiteren wurde am Anfang eine Zahnrad mit etwas mehr rechteckigen Zähnen konstruiert, aber wie sich dann später herausstellte eignen sich Dreiecke doch besser, weil sich da mehr Zähne berühren, es weniger zum abrutschen kommt und auch sich weniger verhakt. Da die Zahnradfunktion in FreeCAD Probleme machte, hat man das Zahnrad so konstruiert, dass man einen Kreis mit Loch hat und an diesem Kreis dann nur ein einziger Zacken ist. Dann musste man nur noch im Kreis spiegeln. Die Anzahl der Spiegelungen ist dabei die Anzahl der Zähne des Zahnrads. Der Vorteil bei dieser Konstruktionsweise ist, dass
ich zum einen nur einen Zahn konstruieren muss anstatt alle
32 Zähne und dabei noch achten muss, dass jeder Zahn dem
anderen gleicht und dass die Zähne auch alle in den Kreis passen, dass der Kreis auf geht. Des weiteren kann ich später noch (oder wie es jetzt schon der Fall war) einfacher die komplette Konstruktion ändern, weil ich nur diesen einen Zahn ändern muss und sich der Rest dann durch die mehrfach Spiegelung anpasst. Das spart Zeit und Nerven.

Was wird in der nächsten Stunde voraussichtlich geschehen?
In der nächsten Stunde soll endlich mit dem Handschuh begonnen werden. Dabei soll zuerst der Neigungssensor montiert werden und konfiguriert werden, weil dieser Sensor zum einem keine 3D-Druckteile braucht und zum anderen am meisten Steuern kann, gleichzeitig aber auch am schwierigsten zu programmieren ist.

Ausflug: Es gibt noch komplett andere Möglichkeiten einen Roboterhand mit Hand-Steuerung zu bauen
Schon früh kamen Menschen auf die Idee, Roboterarme zu bauen. Die ersten „Automaten“ gab es schon im 19. Jahrhundert, doch das Prinzip der Steuerung ist bis heute gleich geblieben: Fäden ziehen so am Finger, dass er sich in die gewünschte Position begibt. Früher hat man das noch per echten Hand direkt am Faden ziehen gemacht, heute nimmt man dafür Motoren. Diese Idee könnte ich auch für meinen Roboterhand nehmen, doch fehlen mir dazu die technischen Mittel und Zeit das dann auch umzusetzen. Anhand der Universität Washington kann man sehr gut sehen, was man alles braucht, um so eine Art Hand zu bauen (siehe Schaubild 6).

Schaubild 4: Das selbe
Problem wie bei der
Oberleitung könnte es
auch bei meinem Roboter
geben – hier wird es
gelöst durch extra
Gewichte
(http://www.schule-bw.de/
faecher-und-schularten/m
athematischnaturwissenschaftlichefaecher/physik/
unterrichtsmaterialien/
waermelehre/
ausdehnung/
ausdehnung_festkoerper.
htm (http://www.schule-bw.de/faecher-und-schularten/mathematisch-naturwissenschaftliche-faecher/physik/unterrichtsmaterialien/waermelehre/ausdehnung/ausdehnung_fes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) )

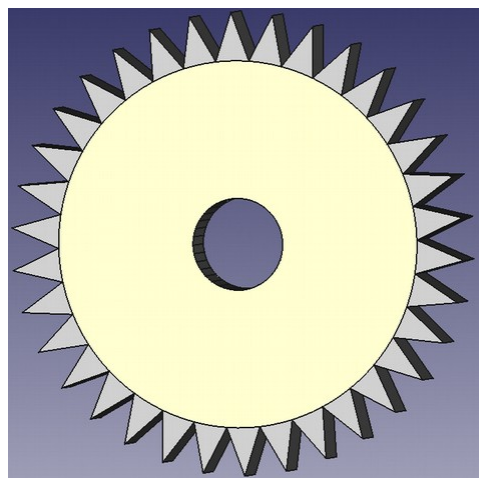
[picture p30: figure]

Schaubild 5: Das erste
Zahnrad

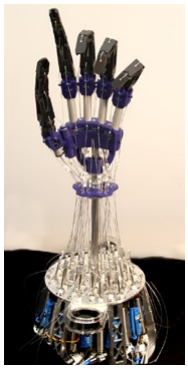
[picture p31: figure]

Schaubild 6: Eine anderer
Roboter, der eine
menschliche Hand
nachahmen soll
(https://homes.cs.washington.edu/~todorov/papers/K
umarICRA13.pdf (https://homes.cs.washington.edu/~todorov/papers/KumarICRA13.pdf) )

Als erstes muss man sagen, dass nicht nur die Universität Washington alleine die Hand gebaut hatte, sondern Hilfe bekam von einer amerikanischen Firma namens „Shadow Robot Company“. Diese Firma ist auf den Bau solcher Hände spezialisiert und es ist ziemlich klar, dass ich so etwas nicht in einem kleinem SIA Schulprojekt haben werde. Des weiteren braucht man aber noch sehr viel Geld, um so eine Hand bauen zu können. Wie die Universität Washington in ihrem technischen Paper (Link unter Schaubild 6) in Punkt 10 „How to make the system less expansive“ (Wie macht man das System am wenigsten teuer) schreibt und man sehen kann, dass das ganze Projekt sehr viel Geld braucht und deshalb das Ziel sein muss, so kostengünstig wie nur möglich arbeiten zu können.
Component | Unit price | Total
FESTO valves | $800 | $32,000
SICK sensors | $250 | $10,000
AirPel cylinders | $50 | $2,000
Pressure sensors | $50 | $2,000
NI PXI system | | $10,000
Custom machining | | $4,000
Es ist jetzt natürlich klar, dass ich nicht deren teuren Sensoren brauche, aber alleine die beiden letzten Punkte, die das meiste vom Roboter ausmachen kosten zusammen $14,000. Hier wird erst klar, wie teuer so ein Projekt eigentlich ist. Geld gespart haben sie, indem sie sehr viel 3D-Druck verwendet haben. Das könnte ich im Prinzip auch machen (anders gesagt: ich mache es schon etwas), aber dann hätte ich das Problem, dass ich nichts mehr im Unterricht wirklich zusammen bauen kann, was aber erwünscht ist. Da eignet sich ein Roboter aus Holz einfach viel besser, da ich ihn (größtenteils) ohne 3D-Drucker aufbauen kann. Ich könnte hier zwar die Finger aus Holz schnitzen und in die selbe Form bringen, wie der 3D-Drucker es macht, es würde aber zu viel Zeit in Anspruch nehmen und das Jahr wäre schon vorüber bevor ich auch nur drei Finger habe.
Als Fazit kann ich sagen, dass es eine nette Idee wäre, den Roboter wie eine Hand zu designen, weil er auch Handbewegungen emittieren soll, für mich aber technisch nicht machbar wäre.

Es gibt noch eine andere Möglichkeit, Sensoren in einen Handschuh zu packen. Heutzutage baut man oft dafür Handschuhe, die mit Glasfaser durchzogen wurden sind. An einem Ende hat man dann eine LED und am anderen Ende hat man einen LDR. Der Handschuh ist durch dieses Add-On äußerlich nicht zu unterscheiden mit einem normalen handelsüblichen Handschuh. Wenn sich die Hand aber des Handschuhträgers bewegt, bricht sich das Licht – es kommt weniger Licht beim LDR an. Das vom LDR gemessene Licht kann jetzt in Relation mit der Bewegung der Hand genommen werden. Mit diesen Messwerten kann man jetzt die entsprechenden Motoren steuern, die an den Fäden der Roboterhand ziehen (also bei einem Roboter wie oben zum Beispiel schon beschrieben wurden ist). Ich kann so eine Steuerung leider nicht umsetzen, weil ich zum einen kein Glasfaser habe, zum andere wird es ziemlich kompliziert mit der passenden Auswertung der Messwerte. Mein eigentliches Problem ist aber, dass ich nicht eine wie oben beschriebene Roboterhand mit Fäden habe aus genannten Gründen und ich schon von vornherein ganz andere Gelenke nachbilden werde, wo eine solche Steuerung mir wenig bringt. Bei mir könnte es sein, dass das Gelenk entweder nach links oder rechts schwenkt, was bei Finger aufgrund der Anatomie der menschlichen Hand einfach nicht möglich ist, daher habe ich das Problem, dass ich mit dieser Technik nicht erkennen, ob ich jetzt nach links oder rechts geschwenkt habe. Das Licht bricht sich, egal ob ich jetzt rechts oder links bin.

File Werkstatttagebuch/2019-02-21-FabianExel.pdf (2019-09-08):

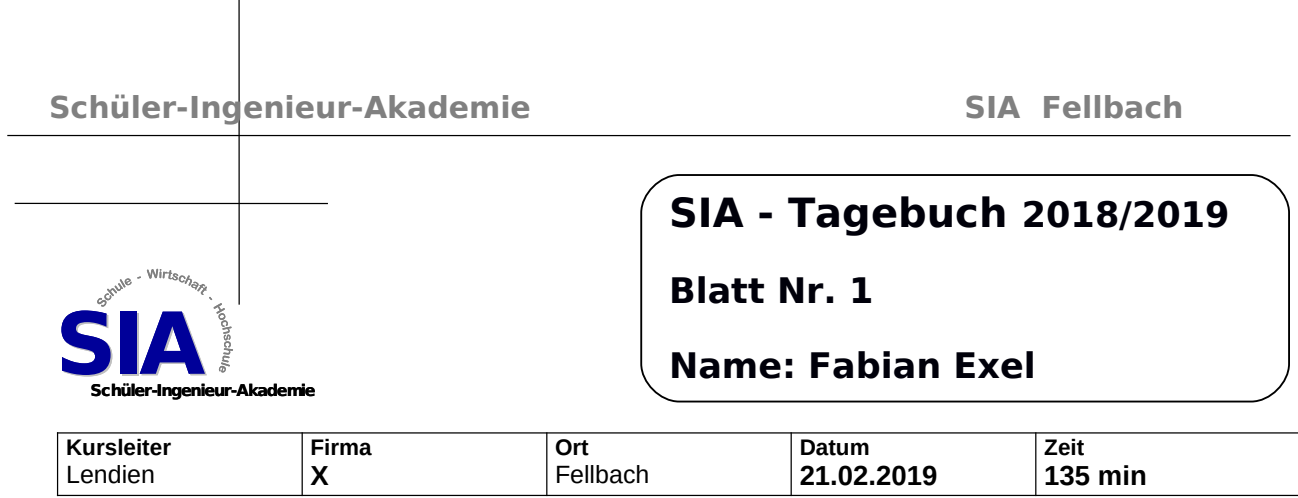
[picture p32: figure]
Schüler-Ingenieur-Akademie; SIA Fellbach; SIA; Schüler Schüler-Ingenieur Ingenieur-Akademie Akademie; Kursleiter Lendien; Firma X; Ort Fellbach; Datum 21.02.2019; Zeit 135 min; SIA - Tagebuch 2018/2019; Blatt Nr. 1; Name: Fabian Exel

## Thema

## Einbau von Zahnrädern

Was wurde gemach?

An sich wurde nicht viel gemacht, aber es wurden zumindest schon mal die Zahnräder montiert. Weil die obere Platte nicht reichte, weil der Servo viel zu weit nach unten rein ragte und die Schrauben auch nicht lang genug waren, um das zu kompensieren, wurde noch eine zweite Platte ausgesägt, um dort dann die Zahnräder dran zu bauen. Damit sich die Zahnräder besser bewegen können habe ich außerdem Metallscheiben immer zwischen gelegt. Das Ziel ist es damit dann die Reibung zu minimieren. Das Zahnrad am Servo wurde zuerst bei mir Zuhause mit Heißkleber ausgefüllt, während ein anderer Servo gleicher Bauart noch drinnen war. Da ich weiß, dass der Heißkleber alleine den Servo nicht halten kann, konnte ich ihn wieder ganz leicht abstecken. Anders ausgedrückt habe ich mir eine eigene Gussform damit gemacht. In der Schule wurde dann das letzte Zahnrad über Sekundenkleber mit dem Servo befestigt. Hier gibt es noch die Befürchtung, dass dieser nicht ausreichen wird, dafür habe ich mir aber inzwischen noch eine andere Methode mit Kupferdraht überlegt, wenn das nicht halten sollte. Diese Methode verwende ich aber erst, wenn der Sekundenkleber nicht hält. Ansonsten wäre das unnötige Zeitverschwendung. Vor dem Einbau habe ich aber den Arduino ein kleines Programm ausführen lassen, der den Servo zuerst auf 180° dreht und dann zurück auf 90°. Durch dieses Programm weiß man dann, in welche Richtung der Servo sich drehen wird und wo 90° ist (Man braucht einen Startwert zum Programmieren). Das ist wichtig zu wissen, damit die Mechanik nicht durch das zum Beispiel immer weiter Zudrücken der Greifer kaputt geht.

Was wird in der nächsten Stunde voraussichtlich geschehen?
Der Handschuh soll gebaut werden. Dann ist die komplette Hardware fertig und man kann mit der Programmierung des ganzen weiter machen. Für den Handschuh werde ich eventuell noch ein paar weitere / verbesserte 3d Druck Teile machen (die ersten gibt es ja schon und wurden auch schon ausgetestet).

### Arbeitsblätter: X

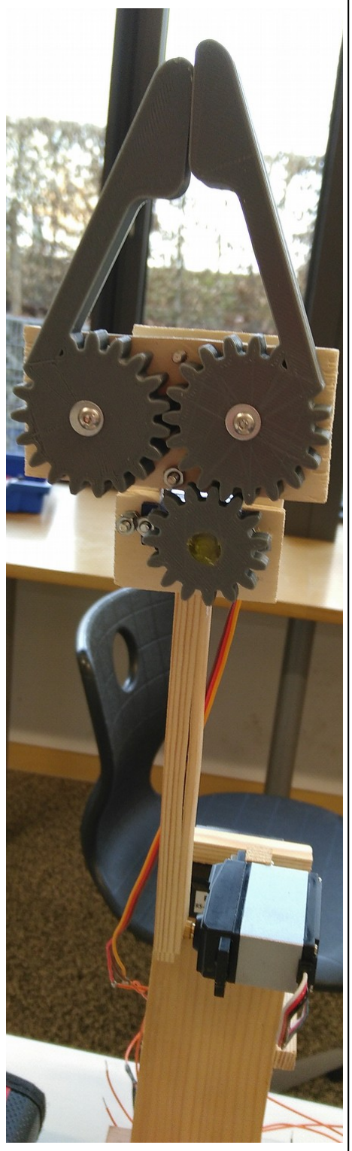
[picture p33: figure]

Schaubild 1: Die
montierten Zahnräder

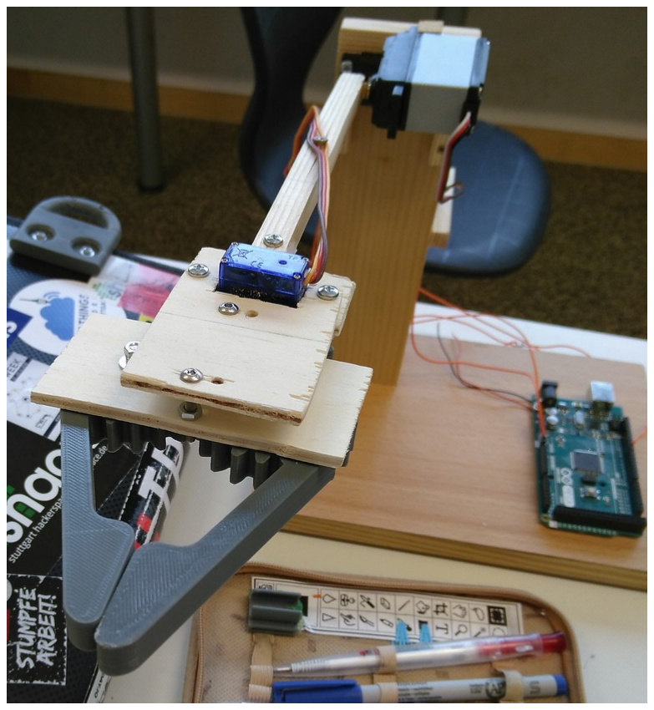
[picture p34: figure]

Schaubild 2: Der fertige Greifer

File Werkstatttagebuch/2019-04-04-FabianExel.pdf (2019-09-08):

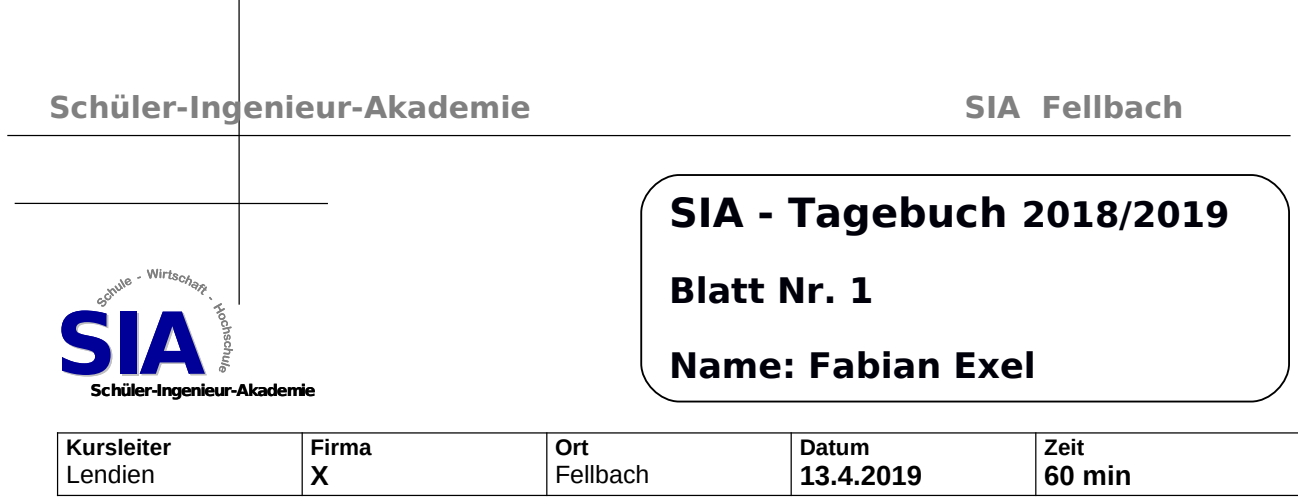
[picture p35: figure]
Schüler-Ingenieur-Akademie; SIA Fellbach; SIA; Schüler Schüler-Ingenieur Ingenieur-Akademie Akademie; Kursleiter Lendien; Firma X; Ort Fellbach; Datum 13.4.2019; Zeit 60 min; SIA - Tagebuch 2018/2019; Blatt Nr. 1; Name: Fabian Exel

## Thema: Unprofessionalität

Was wurde gemach?
Wie das letzte Mal schon angekündigt, wurde der Greifer mit Draht umwickelt. Um Zeit zu sparen und weil es eigentlich auch nicht wirklich nötig ist wurde der Draht nur um die Greifer ohne spezielle Sachen wie zum Beispiel Bohrungen zur Fixierung gewickelt und zum Halt noch mit etwas Heißkleber versehen. Es erfüllt seinen Zweck.

Gleich daraufhin wurde schon im Programm einen Notfallausstieg eingebaut, falls der Kontakt des Greifers schon auf Anschlag ist (Warum ich den Draht um gewickelt habe steht im letzten Tagebucheintrag). Es wird jetzt bei jeder Bewegung des Greifers geprüft, ob die Greifer schon am Anschlag stehen.

Ansonsten wurde nur noch die Schrauben am Handschuh mit Heißkleber fixiert, die man nicht kontern, bzw. fest anziehen kann, weil das der Handschuh aufgrund seiner Form nicht zulässt. Das mache ich nur, damit sie sich nicht lösen.

Was wird in der nächsten Stunde voraussichtlich geschehen? Es müssen noch die Kabel gelötet werden, die zum Greifer führen wie auch getestet werden, ob die Motoren und die Mechanik funktionieren, ob sie funktionieren. Des weiteren muss ich beim Programmieren voran kommen. Ich habe mir überlegt, ob ich vielleicht eine einfache Simulation des Roboters in Java auf meinem Computer schreibe, wo ich dann diese Simulation mit dem Handschuh und einem Arduino Uno von überall (zum Beispiel von mir Zuhause) aus steuern kann. Ein weiterer Vorteil dieser Möglichkeit ist, dass Java und C++ einen stark ähnlichen Syntax haben, was bedeutet, dass ich bei einigen Passagen nur noch „copy – paste“ machen muss. Des weiteren kann bei einer Simulation der Roboter aufgrund eines Fehlerhaften Programms nicht kaputt gehen. Aber mehr davon, wenn ich das wirklich mache.

### Arbeitsblätter: X

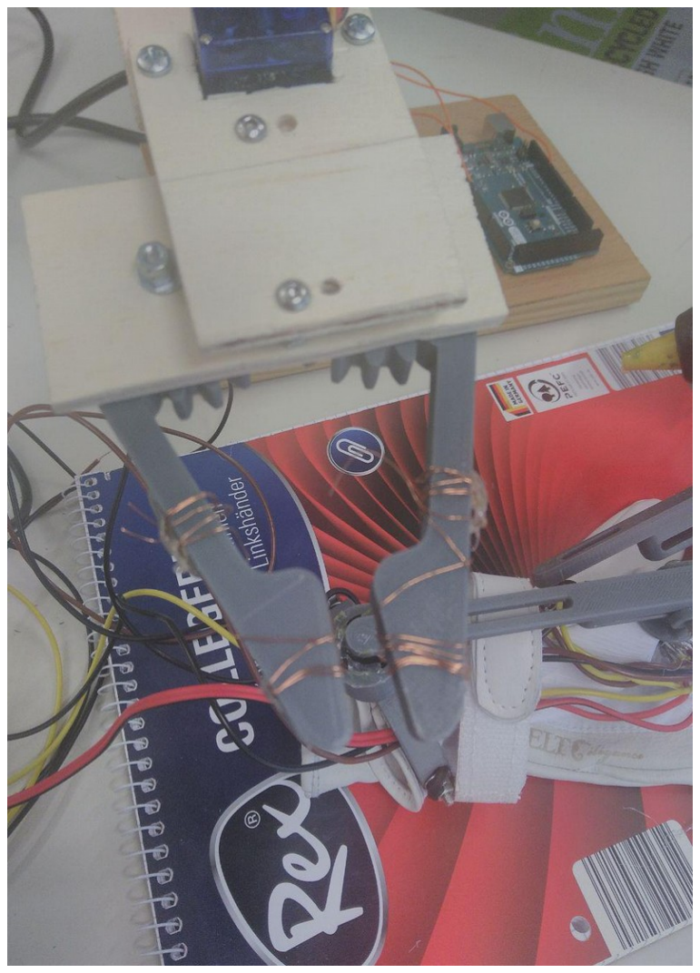
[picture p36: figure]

Schaubild 1: Der Draht um den Greifer sieht zwar etwas unprofessionell aus, kann aber schlimmeres Verhindern.

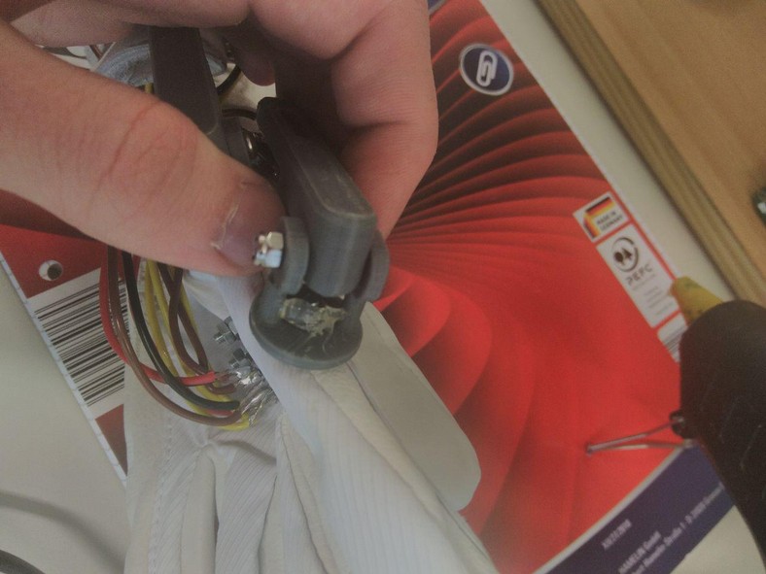
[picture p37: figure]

Schaubild 2: Heißkleber ist auch hier unprofessionell, aber verhindert das Lösen der Schraube

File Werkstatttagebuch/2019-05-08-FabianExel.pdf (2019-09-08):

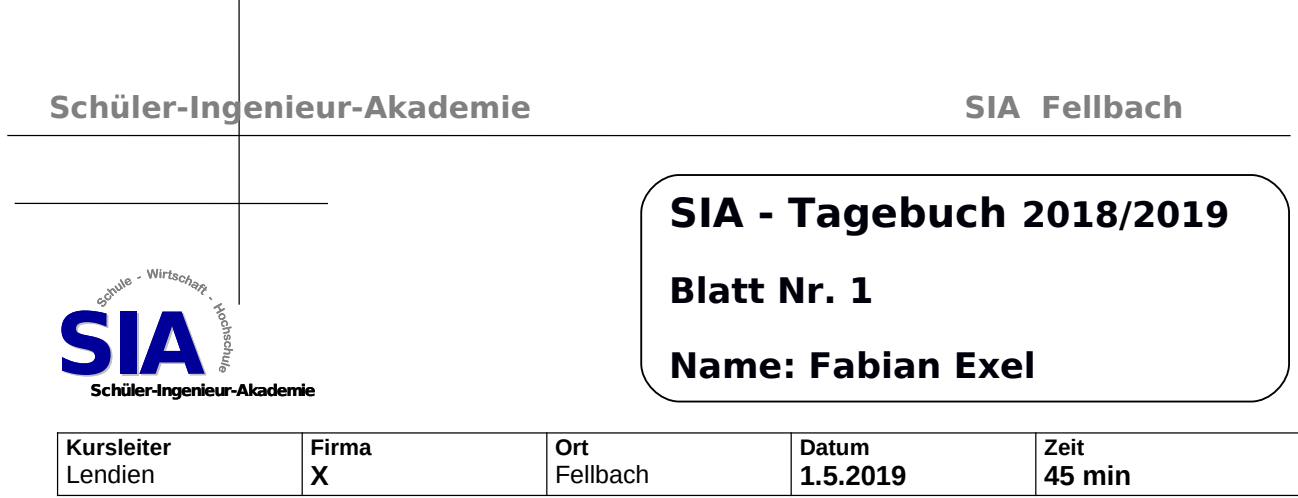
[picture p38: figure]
Schüler-Ingenieur-Akademie; SIA Fellbach; SIA; Schüler Schüler-Ingenieur Ingenieur-Akademie Akademie; Kursleiter Lendien; Firma X; Ort Fellbach; Datum 1.5.2019; Zeit 45 min; SIA - Tagebuch 2018/2019; Blatt Nr. 1; Name: Fabian Exel

### Thema

## Auslesen von Daten

Was wurde gemacht?
Es wurden jeweils zwei Programme geschrieben, welche noch später wichtig werden. Mit dem einem kann ich nämlich die Daten der Sensoren meines Handschuhs auslesen. Das ist wichtig, weil ich wissen muss, welche Werte mir mein Sensor gibt, um ihn dann mit einem Servo abstimmen zu können. Das zweite Programm kümmert sich dann um den Servo. Ein Potentiometer soll als „Joystick“ fungieren und damit dann eine gewünschten Servo ohne Grenzen steuern zu können. Das wichtig, weil nur so kann ich schauen, bei welchem Winkel welcher Servo am Anschlag steht, damit er darüber nicht hinaus kann und dabei nichts kaputt machen kann. Am Ende muss ich im Programm nur noch die Werte vom Befehl „map“ anpassen. Das sieht dann so aus: map(variable, kleinster Wert Sensor, größter Wert Sensor, kleinster Wert Servo, größter Wert Servo); // Wert Servo ist immer der Winkel des Servos
Der map-Befehl rechnet mir dann im Programm die Eingaben der Sensoren automatisch in die Werte um, die ein Servo braucht (Wichtig ist, auch zu
schreiben, in welcher Lage des Handschuhs sich
befindet, damit man weiß, was auf und zu ist).

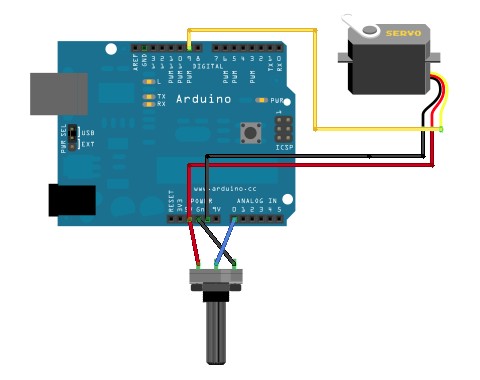
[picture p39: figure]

Ich habe schon mal eine Tabelle gemacht für die Werte des Handschuhs:
Sensor | Kleinster Wert | Größter Wert
Greifer | 245 (zu) | 285 (auf)
Kipp | 777 (hoch) | 800 (runter)
x | 277 (links) | 400 (rechts)
y | 280 (unten) | 400 (oben)
z | 277 (gerade) | 400 (umgedreht)

Als Zusatz muss ich sagen, dass ich einen Arduino Uno (siehe Schaubild oben) anstatt einen Arduino Mega verwende, weil er klein ist und diese einfache Aufgabe genauso gut wie der Mega erledigen kann. Außerdem habe ich zum testen Zuhause nur den Arduino Uno zu Verfügung.

An den Werten ist später dann noch aufgefallen, dass ich mir im Prinzip den Kippsensor (Potentiometer) hätte sparen können, weil ich die benötigten Werte auch mit den Neigungssensor aufnehmen kann. Des weiteren haben beide Potentiometer nur kleine Messspannen, insbesondere der Kippsensor, weshalb es sich jetzt hier anbietet, den Kippsensor beim Hauptprogramm zu vernachlässigen und auf den Neigungssensor zurück zu greifen.

Schaubild 1: So soll wird der Servo angesteuret werden. Wenn man Schaltplan des Handschuh Tests sehen möchte schaue man sich ältere Tagebucheinträge an, wo ich den Schaltplan des Roboters erläutere.

- Hand_Data.ino -
int accZPin=0;
int accYPin=1;
int accXPin=2;
int onePot=3;
int twoPot=4;

void setup() {
// put your setup code here, to run once: Serial.begin(9600);
}

void loop() {
// put your main code here, to run repeatedly: Serial.print(" X=");
Serial.print(analogRead(accXPin)); Serial.print(" Y=");
Serial.print(analogRead(accYPin)); Serial.print(" Z=");
Serial.println(analogRead(accZPin)); Serial.print(" Potentiometer 1: "); Serial.print(analogRead(onePot)); Serial.print(" Potentiometer 2: "); Serial.println(analogRead(twoPot)); delay(500);
}
- Servo_Test -
#include <Servo.h>

Servo myservo; // create servo object to control a servo

int potpin = 0; // analog pin used to connect the potentiometer int val; // variable to read the value from the analog pin

void setup() {
myservo.attach(9); // attaches the servo on pin 9 to the servo object Serial.begin(9600);
}

void loop() {
val = analogRead(potpin); | // reads the value of the potentiometer (value between 0 and 1023)
val = map(val, 0, 1023, 0, 180); | // scale it to use it with the servo (value between 0 and 180)
myservo.write(val); | // sets the servo position according to the scaled value
Serial.print("Poti: ");
Serial.print(analogRead(potpin));
Serial.print("Servo: ");
Serial.println(val);
delay(15); | // waits for the servo to get there
}
Arbeitsblätter: X

Was wird in der nächsten Stunde voraussichtlich geschehen?
Nächste Stunde soll der Roboter auf Herz und Nieren geprüft werden, wie auch wie oben schon beschrieben die Daten der Motoren aufgenommen werden. Wenn ich diese habe kann ich dann vollends damit anfangen, das Endgültige Programm fertig zu schreiben.

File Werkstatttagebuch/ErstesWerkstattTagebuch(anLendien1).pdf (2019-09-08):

Werkstatt Tagebuch Fabian Exel – Der handgesteuerte Handroboter

Tag 1; 14.11.2018

Am ersten Tag ging es vor allem um die Planung im Groben. Zuerst musste bestimmt werden, wie die Motoren angeordnet sein sollen. Es wird 3 Servos geben – die Herausforderung ist, dass die 3 Motoren eine Hand ziemlich genau abbilden können. Des weiteren ist wichtig zu wissen, wie man die Bewegungen der Hand aufnehmen möchte. Deshalb gibt es einen Greifarm, der praktisch den Winkel zwischen Daumen und

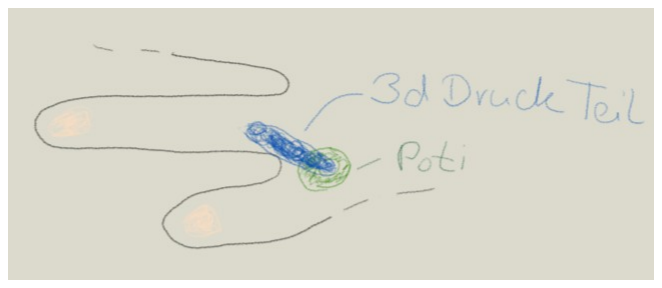
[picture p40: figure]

Zeigefinger abbildet. An der Hand wird
dieser | durch | ein | Potentiometer
aufgenommen, welcher aus dem 3D Drucker noch einen speziellen Aufsatz haben wird. Dann gibt es noch je einen Motor für die Kippbewegung der Hand und für die Drehbewegung. Bei der Hand wird die Kippbewegung wieder mit einem Potentiometer aufgezeichnet, nur bei der Drehbewegung kommt ein Neigungssensor zur Hilfe.

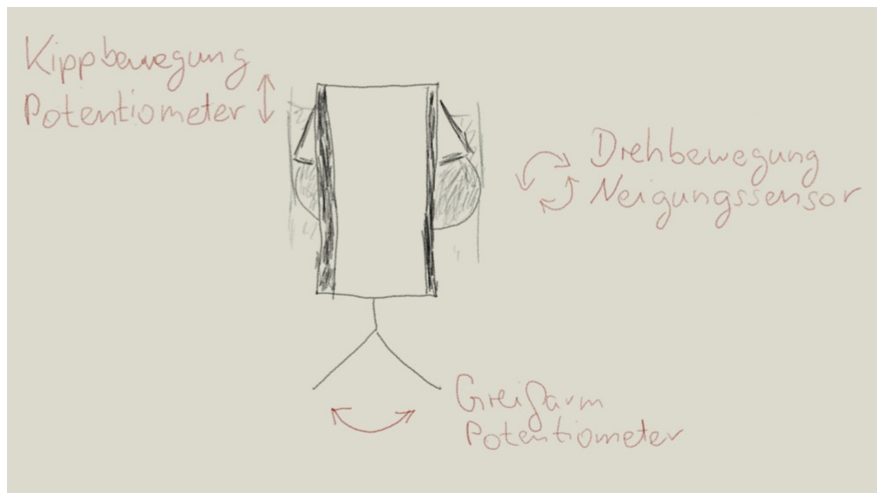
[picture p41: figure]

Der Roboter wird später dann so aufgebaut sein, dass er auf einer Platte steht, auf dem eine Säule hoch geht. Auf der Platte soll aber auch der Arduino festgeschraubt werden (siehe Schaubild 1). Auf der Säule dann drauf soll der Servo abgebildet werden, der die Drehbewegung darstellt. Das wichtige bei diesem Servo wird sein, dass er sehr stark ist, weil er auch das Gewicht vom restlichen Roboterarm halten muss. Direkt nach der Drehbewegung soll der Servo kommen, der die Kippbewegung zeigt. Um bessere Stabilität zu
erlangen bekommt er auf die andere Seite wenn
möglich aus Metall ein zweites Lager. An den
beiden Lager gehen je eine Stange nach vorne raus, die dann mit der Mechanik des Greifarms befestigt sind. Die ganze Beschreibungen wurden in mehreren Skizzen festgehalten.

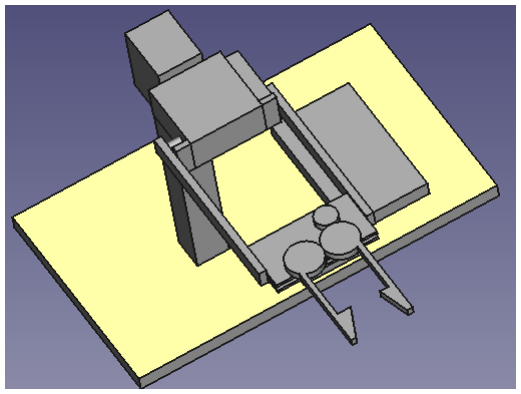
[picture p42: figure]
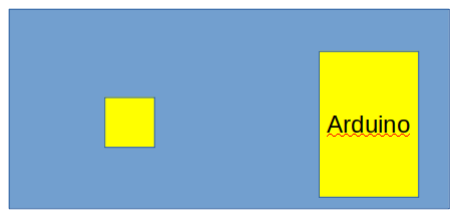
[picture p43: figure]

Seite 1 | Werkstattbuch Fabian Exel

Schaubild 4: Arduino neben
Robotersäule

Schaubild 2: Welche Sensoren welche Bewegung abbilden sollen

Schaubild 3: Aufbau des Roboters - so sollte er aussehen, wenn er fertig

Schaubild 1: Wie ein Potentiometer die Bewegung aufnehmen könnte

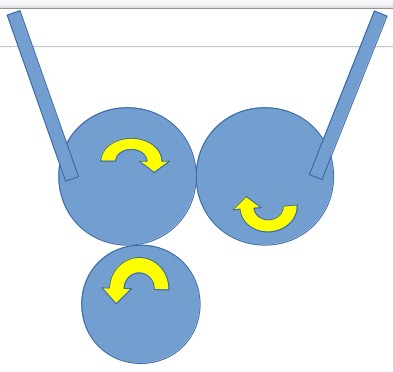
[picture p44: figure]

Der Greifarm soll im Grunde aus 3 Zahnräder bestehen (siehe Schaubild 5). Die beiden vorderen Zahnräder haben zusätzlich noch eine Stange dran , die aber eine Form haben sollen, dass wenn sich der Greifer sich schließt, es eine durchgängige Verbindung gibt. Am hinteren Zahnrad ist der Servo angeschlossen. Das ganze ist so angeordnet, dass sich die vorderen Zahnräder in entgegengesetzter Richtung öffnen können. Des weiteren soll der Greifer nur einen sehr kleinen Servo bekommen, damit die beiden anderen Servos nicht so viel Tragen müssen. Wenn sie nämlich nicht die Kraft tragen können,
die sie müssen, wäre das Projekt gescheitert. Schließlich ist es auch
nicht nötig, schwere Gegenstände mit dem Greifarm zu erfassen.

Für den Roboterarm sind schon einige gebrauchte Servos gefunden wurden, welche nur noch getestet werden müssen. Dafür wird noch eine Schaltung mit Arduino aufgebaut, womit man den Servo testen kann (Siehe Abbildung 6). Gesteuert wird dieser von einem Potentiometer.

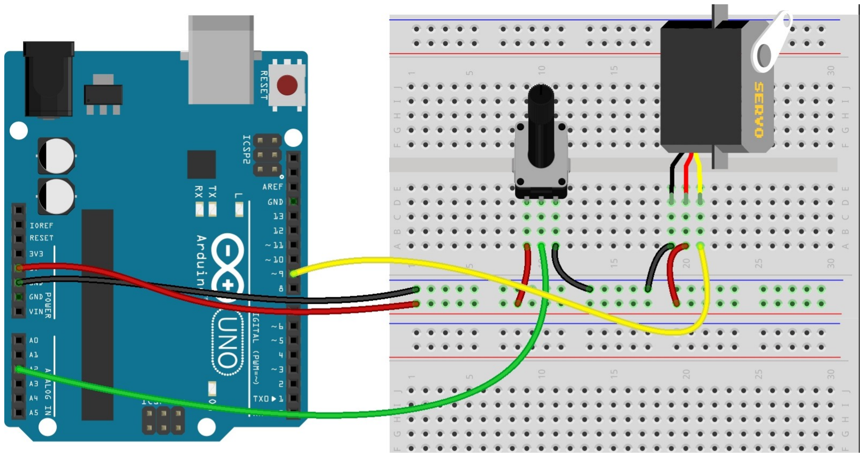
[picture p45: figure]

Seite 2 | Werkstattbuch Fabian Exel

Schaubild 5: 3
Zahnräder für den
Greifer

Schaubild 6: Der Servo-tester

Schaubild 7: Schaltplan des Servo-testers

Arduino Programm für den Servo-tester:

#include <Servo.h>

Servo myservo; // create servo object to control a servo

int potpin = 0; // analog pin used to connect the potentiometer
int val; // variable to read the value from the analog pin

void setup() {
myservo.attach(9); // attaches the servo on pin 9 to the servo object
}

void loop() {
val = analogRead(potpin); // reads the value of the potentiometer (value between 0 and 1023) val = map(val, 0, 1023, 0, 180); // scale it to use it with the servo (value between 0 and 180)
myservo.write(val); | // sets the servo position according to the scaled value
delay(15); | // waits for the servo to get there
}

Was jetzt noch fehlt ist eine Einkaufsliste. Einige Sachen sind schon vorhanden, andere müssen noch besorgt werden:

Vorhanden | Noch besorgen
- Holzplatte • Ständer • Arduino Mega • Servos • Handschuh • Kabel • diverses anderes Holz • Metallplatten (z.B.: für anderes lager) • Metallstangen • 2 Potentiometer (mit Anschluss für Griff) • Neigungssensor (gy-61) • diverse Schrauben | • Zahnräder für Greifer
Seite 3 | Werkstattbuch Fabian Exel

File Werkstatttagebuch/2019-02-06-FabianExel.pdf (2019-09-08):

Schüler-Ingenieur-Akademie; SIA Fellbach; SIA; Schüler Schüler-Ingenieur Ingenieur-Akademie Akademie; Kursleiter Lendien; Firma X; Ort Fellbach; Datum 06.02.2019; Zeit 135 min; SIA - Tagebuch 2018/2019; Blatt Nr. 1; Name: Fabian Exel

## Thema

## Zahnräder

Was wurde gemach?

Es wurde zuerst ein Kurzschluss behoben. Zum Glück ist nichts kaputt gegangen. Der Fehler trat bei der Verkabelung der Servos auf. Wie ich in einem früherem Tagebucheintrag schon beschrieben habe, ist die Verkabelung unterschiedlich zwischen den Servos (aufgrund unterschiedlichen Servotypen / Herstellern), somit sollte ich eigentlich aufpassen.

Später wurde dann noch mit den Zahnrädern für den Greifer begonnen. Da am Anfang noch nicht ganz klar war, wie die Zahnradfunktion in FreeCAD richtig funktioniert, hat man zuerst versucht, sich selbst über andere Funktionen ein Zahnrad zu konstruieren. Dafür habe ich habe ich zuerst eine Kreis mit nur einen Zacken eines Zahnrades gezeichnet und den im Kreis mehrfach gespiegelt. Der Vorteil bei dieser Methode ist, dass es zum einen schneller und einfacher geht als jeden Zacken zu zeichnen und zu berechnen, wie groß der Zacken ist / wie viele Zacken in den Kreis passen. Auf gleichmäßige Zahnverteilung sollte man eigentlich drauf achten damit der Kreis auch rund komplett aufgeht. Ein weiterer Vorteil dieser Methode ist das schnelle Abändern von Zähnen, indem ich einfach nur einmal meine Änderung mache und diese Änderung dann für alle anderen Zähne auch schnell übernommen wird. Am Ende hatte ich vier Konzepte für Zahnräder: bei den einen waren die Zacken eher abgerundete Rechtecke, bei den anderen waren die Zacken eher Dreiecke, ansonsten wurde noch mit der Größe und Anzahl der Zähne stark variiert.

Als ich dann meine Zahnräder einen Daimler-Motorenkonstrukteur gezeigt habe, welches wohl das beste wäre, hat er gesagt, dass alle wohl eher schlecht funktionieren werden. Er fügte hinzu, dass das Thema Zahnrad ein etwas Größeres ist, weshalb ich es hier auch nicht hier in seiner kompletten Fülle darstellen kann.

Zuerst einmal sind Zahnräder aber dafür da, Kräfte zu übertragen und Geschwindigkeiten über die Übersetzung zu ändern. Zahnräder haben eine spezielle Konstruktion, um möglichst gut zu funktionieren. Da war die Idee, dass man sich einen Kreis nimmt und den erst einmal rollen lässt. Dann schaut man sich mehrere Punkte an (siehe Schaubild 2 nächste Seite) – hier steht der Punkt M für den Mittelpunkt des Kreises, den Punkt braucht man, um anzuzeigen, wie weit der Kreis jetzt gerollt war. Der andere Punkt ist A, der ganz außen vom Kreis liegt. Jetzt bewegt man den Kreis etwas nach rechts und schaut, wie die beiden Punkte A und M liegen. Was auffällt ist, dass zwar der Mittelpunk M immer konstant in gleichen Abständen nach rechts wandert, während A sich in einer Art Kurve bewegt. Was hat diese Erkenntnis jetzt mit Zahnrädern zu tun? Man weiß jetzt, wie sich verschiedene Punkte im Kreis bewegen wodurch man weiß, wie sich ein Kreis abrollt. Ein Zahnrad ist zwar an sich nicht direkt ein Kreis (außer man füllt dessen Zahnlücken mit etwas gleichmäßig auf), aber wenn zwei Zahnräder zusammen kommen sollen sie bei der Stelle, wo sie ineinander greifen wieder so wirken, als wären die beiden Zahnräder zwei übereinander gelappte Kreise, d.h sie sollen sich gegenseitig ergänzen. Wäre es anders, dann würden sich die Zahnräder nicht richtig abrollen und sich wahrscheinlich verhaken. So kommt man jetzt auf die Form.

Was jetzt auch noch wichtig ist, ist der Winkel α. Er gibt an, in welchen Winkel die
linke Kurve (also die Kurve, die zum Beispiel vom Punkt A erzeugt wurden ist)
und der Mittelpunkt zueinander stehen. Hier als Linie ist dann die Tangente
gemeint beim Punkt A. Durch ausprobieren haben Konstrukteure gesehen, dass sich wohl ein 20° Winkel am besten eignet. Wäre übrigens α = 0°, dann gäbe es kein Zahnrad mehr, sondern eine Zahnstange.

Bei einem Zahnrad, was mit einem anderem Zahnrad zusammen arbeiten soll, sollte man als weiteren Punkt noch wissen, wie viele Zähne jetzt jeweils ein Zahnrad hat. Dafür rechnet man bei beiden Zahnräder den Durchmesser den Durchmesser des äußeren Kreises (d) geteilt durch den Abstand äußerer Kreis / innerer Kreis (m) des Zahnrades und vergleicht jetzt die beiden.

### Arbeitsblätter: X


Schaubild 1: Die fertig
ausgedruckten Zahnräder


Man muss bei der Rechnung einige Sachen beachten: der Abstand äußerer Kreis / innerer Kreis (m) muss immer bei beiden Zahnräder der selbe sein, damit die Zähne auch optimal in einander greifen können und bei beiden Zahnrädern muss als Ergebnis der Rechnung immer eine natürliche Zahl heraus kommen, weil es keine halben / negativen Zahnräder gibt. Zum ausprobieren für meine Zahnräder habe ich eine Tabelle erstellt, mit den Durchmessern, die meine Zahnräder haben sollen (ich habe später nur kleinere genommen, weil aufgefallen ist, das ansonsten der Platz nicht reichen wird / der Greifer viel zu groß wird. Die Rechnung ist aber im ganzen nach dem selben Prinzip nach verlaufen).
| m=5 | m=4 | m=3 | m=2,5
d1=50mm | Z1=50/4=10 | Z1=50/4=12,5 | Z1=50/3=16,8 | Z1=50/2,5=20
d2=70mm | Z2=70/4=14 | Z2=70/4=17,5 | Z2=70/3=23,3 | Z2=70/2,5=28

Schaubild 2: Herleitung der Zahnform eines Zahnrades


Schaubild 3: Zahnradkonstruktion auf Blattpapier zum ausprobieren

Man kann jetzt hier sehen, dass man für m nicht 4 oder 3 nehmen sollte, sondern eher 5 oder 2,5. m=5 ist dennoch nicht gerade das Beste, weil hier die Zähneanzahl recht gering ist. Generell kann man sagen, dass Zahnräder mit mehr Zähnen sich besser drehen lassen, weil mehr Zähne ineinander greifen können. Entwickler von Zahnräder sollten also darauf achten, die Zahnbreite und den Zahneingriff nicht zu klein zu machen. Und zum Glück kann man auch dies berechnen. Den Zahneingriff wird mit Umfang des Zahnrades durch die Anzahl der Zähne berechnet und die Zahnbreite ist der Zahneingriff durch 2 geteilt.

Wie am Anfang des Textes beschrieben können Zahnräder über eine Übersetzung die Geschwindigkeit ändern. Dies kann man dann auch mit der Formel i=Umfang größeres Zahnrad / Umfang kleineres Zahnrades oder mit der Formel i=Anzahl der Zähne großes Zahnrad / Anzahl der Zähne kleines Zahnrad (wenn man von einem großen Zahnrad auf ein kleineres geht; wenn man von einem kleinem Zahnrad zu einem großem Zahnrad übersetzen möchte vertauscht man einfach die beiden Quotienten) berechnen. Bei beiden Formeln wird das selbe Ergebnis herauskommen. Das Ergebnis kann man dann mit der Drehgeschwindigkeit v multiplizieren, und weiß dann, wie schnell sich das Zahnrad dreht. Anders ausgedrückt: Das Ergebnis drückt die prozentuale Änderung der Drehgeschwindigkeit aus. Wenn man von einem kleinem Zahnrad auf ein größeres geht, dann wird die Geschwindigkeit kleiner (i muss also < 1 sein); anders herum wird sie natürlich schneller (i muss also > 1 sein).
Zahnrad GROẞ: U=70cm; d=14 | Schnellere Übersetzung | 0,7m / 0,5m =14 / 10 = 1,4
Zahnrad klein: U=50cm; d=10 | Kleinere Übersetzung | 0,5m / 0,7m = 10 / 14 ~ 0,7

Am Ende stellte sich heraus, dass ich mir eigentlich nicht eine solche Mühe machen muss, weil nach (wiederholter) herum probieren in FreeCAD hat die Zahnradfunktion wieder funktioniert (zugegeben habe ich auch kurz im Internet nachgeschaut). Jetzt muss ich nur noch die Anzahl der Zähne bestimmen und das Programm hat mir das Zahnrad an die passende Größe angepasst. Mein Fehler war es, dass ich keinen Körper erstellt habe und deshalb das Programm nicht wusste, wohin es das Zahnrad jetzt basteln soll. Immerhin habe ich bei der Sache mit Zahnrädern selbst sehr viel gelernt, was ich später bestimmt auch noch brauchen werde.


Schaubild 4: Die Zahnradfunktion in FreeCAD

Was wird in der nächsten Stunde voraussichtlich geschehen?
In der nächsten Stunde sollen die fertig ausgedruckten Zahnräder (siehe Schaubild 1) angebaut werden. Dann ist der Roboter an sich komplett fertig. Es muss aber beim Einbau auf die Stellung des anliegenden Servos geachtet werden, weil man die Stellung vom Servo nicht kennt, wie auch in welche Richtung sich der Servo drehen wird. Das alles muss noch herausgefunden werden, damit die Mechanik nicht durch das zum Beispiel immer weiter Zudrücken der Greifer kaputt geht. Wie sie montiert werden sollen, wurde schon im ersten Eintrag ausführlich behandelt und das rechte Schaubild zeigt dieses noch einmal kurz auf.


Schaubild 5: So sollen die Zahnräder angeordnet werden (Achtung: hier sind es noch ältere Konstruktionen)

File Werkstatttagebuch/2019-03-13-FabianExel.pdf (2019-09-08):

Schüler-Ingenieur-Akademie; SIA Fellbach; SIA; Schüler Schüler-Ingenieur Ingenieur-Akademie Akademie; Kursleiter Lendien; Firma X; Ort Fellbach; Datum 13.03.2019; Zeit 135 min; SIA - Tagebuch 2018/2019; Blatt Nr. 1; Name: Fabian Exel

### Thema

## Konstruktionen für den Handschuh

Was wurde gemach?
Es wurden die restlichen Teile für den Handschuh konstruiert. Wie in den vorherigen Tagebucheinträge schon beschrieben, werden zwei Potentiometer und ein Neigungssensor eingebaut. Den Neigungssensor konnte man einfach über 2 Löcher im Handschuh über Schrauben verbinden und den einen Potentiometer über drei Löcher im Handschuh, wo man den Potentiometer einfach nur noch reinstecken musste und die Enden umkniggen musste. Jetzt fehlt nur noch der letzte Potentiometer, aber nach etwas herumprobieren, wie und wo man ihn jetzt am besten fest macht kam schnell raus, dass es wohl am besten ist ein extra Teil aus dem 3D Drucker zu machen, weil der Handschuh am Handgelenk sehr locker an sitzt und sich dadurch beinah beliebig frei bewegen kann – was aber schlecht ist für die Erfassung der Werte. Dieses Problem habe ich dann mit einen halben Armreif gelöst, der an das untere Ende des Handschuhs kommen soll, damit er nicht verloren geht. Befestigt werden soll er aber über zwei Schrauben, damit er zum einen sich, wenn es benötigt wird, um den Handbewegungen folgen zu können, zum anderen nicht den Bewegungen folgt, die die Messungen verfälschen. In den großen Kreis in der Mitte des halben Armreifs wird dann der Potentiometer kommen.

Wenn man mit Potentiometer arbeitet stellt sich auch immer die Frage: Was baue ich in das Drehloch des Potentiometer, um ihn wie gewünscht steuern zu können? Dieses Problem habe ich schon in den ersten Tagebucheinträgen angehen wollen, doch mir ist ein weiteres
Problem beim testen der ersten Konstruktion mit den ersten
eingebauten Potentiometer aufgefallen: Die Mechanik kann sich durch


die Handbewegungen verhaken. Um das zu lösen wurde eine spezielle Art Schiene in das Verbindungsstück konstruiert, womit das Verbindungsstück sich mehr noch oben oder unten bewegen kann, jedoch nicht nach links oder rechts, weil man in diese Richtungen messen möchte.

Später wurde noch ein kürzeres Verbindungsstück konstruiert, weil sich herausgestellt hat, dass für den einen Potentiometer am Armreif der lange perfekt ist, aber für den anderen Potentiometer viel zu lang ist.

Als letztes stellt sich nur noch die Frage, wie ich meine Verbindungsstücke vom Potentiometer mit den Handschuh verbinde. Das Bauteil muss sich drehen können, um sich nicht zu verhaken und zur oben genannten Schiene passen. Genau diese Anforderungen habe ich umgesetzt: Jetzt habe ich ein Bauteil, welches man mit einer Schraube mit dem Handschuh verbinden kann, wodurch es sich drehen kann, und mit einer Schraube durch die Schiene mit dem Verbindungsstück.

Arbeitsblätter: X

Schaubild 1: Der erste Potentiometer und der Neigungssensor sind schon eingebaut - die restlichen Verbindungen , Kabel fehlen aber noch

Schüler-Ingenieur-Akademie | SIA Fellbach


Was wird nächste Woche passieren?
Die oben beschriebenen Bauteile sollen aus dem 3D-Drucker ausgedruckt werden, damit ich den Handschuh komplett fertig bauen kann.

Schaubild 3: Das Teil für
die Verbindung zwischen
Verbindungsstück und
Handschuh

Schaubild 4: Der halbe Armreif für das untere Ende des
Handschuhes

Schaubild 2: Das Verbindungsstück für den Potentiometer

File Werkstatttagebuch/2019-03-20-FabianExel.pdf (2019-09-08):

Schüler-Ingenieur-Akademie; SIA Fellbach; SIA; Schüler Schüler-Ingenieur Ingenieur-Akademie Akademie; Kursleiter Lendien; Firma X; Ort Fellbach; Datum 20.3.2019; Zeit 135 min; SIA - Tagebuch 2018/2019; Blatt Nr. 1; Name: Fabian Exel

### Thema

## Fertigbau des Handschuhs

Was wurde gemach?
Der Handschuh ist fertig! Die ausgedruckten Teile vom letzten mal wurden eingebaut. Bevor man aber die Verbindungsstücke mit den Potentiometer verbinden kann, muss man die Potentiometer mit zum Beispiel einem Schraubenzieher so einstellen, dass dieser in der Mitte ist. Das ist wichtig, damit man nicht direkt bei der ersten Bewegung der Hand an den Anschlag des Potentiometer kommt. Verbunden wurden Potentiometer und Verbindungsstück durch Heißkleber. Selbst wenn dies nicht ganz halten würde, sollte der Arm trotzdem noch funktionieren, weil das Plastik sich praktisch wie eine passende Gussform um das Teil schließt (und den Rest für den nötigen Halt machen die Schraubverbindungen).

Da sich der Armreif zu sehr bewegt hat wurde dieser jetzt mit einem Gummizug weiter fixiert. Das anziehen des Handschuhs wird dadurch zwar auf der einen Seite sehr viel schwieriger, dafür bleibt aber der Armreif auf der anderen Seite an der Stelle und die Messergebnisse werden auch nicht verfälscht. Das Anbringen des Gummizuges war kein Problem, weil ich dafür schlicht die Verbindungsschrauben des Armreifs verwendet habe. Unter die Mutter, die alles fixieren soll, kam noch das Gummi. Dann musste das ganze nur noch angezogen werden, wodurch sich sie Konstruktion dann hielt. Als Gummi für den Gummizug habe ich einfache Haushaltsgummis genommen, die man zum Beispiel
auch bei Marmeladengläser verwendet. Grund hierfür war, dass
ich elastische Schnüre gebraucht habe, was diese Gummis sind


(außerdem waren sie auch sehr schnell verfügbar, wodurch ich Zeit gespart habe).

Da sich beide Potentiometer nicht viel mehr eine Vierteldrehung sich bewegen gibt es die Gefahr, dass die Messwerte zu ungenau werden. Was man dann machen muss, weiß ich noch nicht. Ich kann nur hoffen, dass ich mir nie eine Alternative zu derzeitigen Lösung überlegen muss.

Bei den Kabeln habe ich versucht, umweltfreundlich zu agieren. Das bedeutet aber auch, dass es fast kein einheitliches Farbsystem gibt (weil ich zu wenige Farben zur Auswahl hatte). Die Schwarzen Kabel von den Potentiometer sind beide dessen Datenleitung. Auch der Neigungssensor hat ein schwarzes Kabel mit der selben Funktion. Der einzige Unterschied ist aber das noch extra angelötete Ende, womit ich das Kabel verlängern wollte. Das ist jetzt durch gelbes Isolierband geschützt, wodurch es auch erkennbar ist, dass dieses Kabel vom Neigungssensor stammt. Stromversorgungskabel, die rein um den Handschuh verlaufen, haben die Farbe Braun (Masse) und Gelb (5V). Die Stromversorgungskabel zum Arduino haben dagegen die Farbe Schwarz-Rot (Masse) und Rot (5V). Die restlichen Datenleitungen vom Neigungssensor haben die Farbe Braun und Gelb, weil diese noch übrig blieben. Außerdem verlaufen Kabel, die rein um den Handschuh verlaufen, durch eine extra Lasche, wodurch diese noch mal zusätzlich kenntlich werden. Auch wenn es womöglich etwas verwirrend werden kann, hoffe trotzdem durch meine Farbwahl eine geringe Verwechslungsgefahr beim Einbau.

Schaubild 1: Der fertige Handschuh

Schüler-Ingenieur-Akademie | SIA Fellbach
Arbeitsblätter: X

Was wird in der nächsten Stunde voraussichtlich geschehen?
Da die komplette Hardware jetzt fertig gebaut wurden ist, kann ich im Prinzip mit Programmieren und Tests beginnen. Das werde ich aber nicht sofort machen, weil ich mir noch etwas für den Roboter überlegt habe. Um die Mechanik des Greifers zu schützen, soll bei den Auflageflächen der Greifer dünne Leiter eingebaut werden, welche dann als eine Art Taste zusammen arbeiten sollen. Wenn der Greifer geschlossen wird, soll ein ’Cut’ im Programm aufgerufen werden, welcher dafür sorgt, dass sich der Greifer nicht weiter schließen kann. Dieser soll aus Sicherheitsgründen an erster Stelle schon programmiert werden, damit selbst wenn ich Programmierfehler mache und sich dadurch der Greifer zu sehr schließt, kein Schaden beim Roboter angestellt wird.

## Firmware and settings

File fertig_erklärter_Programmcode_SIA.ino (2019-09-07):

#include <Servo.h>  
/* Einbindung der Servo-Bibliothek, damit das Programmieren der Servos leichter wird */

// Pinfestlegung der Sensoren, acc ist die Abkürzung für den Neigungssensor
int accZPin=0;      //Z-Achse
int accYPin=1;      //Y-Achse
int accXPin=2;      //X-Achse
int onePot=3;       //Greifer-Potentiometer
int twoPot=4;       //Neigungs-Potentiometer

/* Variablenerstellung für die unterschiedlichen Gelenke des Roboters – Namen nach Gelenk */
int greifer;
int greifer_alt = 0;    // was […]_alt bedeutet wird unten beschrieben
int dreher;
int dreher_alt = 0;
int neigung;
int neigung_alt = 0;

//Variablenfestlegung für die benötigte Pause einer Servobewegung
int pause_greifer;
int pause_dreher;
int pause_neigung;

//Namensfestlegung für die verschiedenen Servos
Servo first;     //Greifer
Servo second;    //Dreh
Servo third;     //Neigung

//Code, der einmal ausgeführt wird:
void setup() {
/* Baudrate einstellen – die Geschwindigkeit, womit der Arduino mit einem PC redet */
    Serial.begin(9600); 
//Den Servos jeweils ihren Pin zuweisen
  first.attach(10);
  second.attach(11);
  third.attach(9);
  }


//Code, der ständig wiederholt wird:
void loop() {
  /* zuerst wird zum leichteren Kalibrieren (einstellen) des Neigungssensor ihre Werte ausgelesen und an den PC geschickt */
  Serial.print(" X=");
  Serial.print(analogRead(accXPin));
  Serial.print(" Y=");
  Serial.print(analogRead(accYPin));
  Serial.print(" Z=");
  Serial.println(analogRead(accZPin));

//Hier wird jetzt in diesem Block der Greifer-Servo gesteuert.
  greifer = map(analogRead(onePot), 215, 300, 30, 190); /* Hier wird der Greifer-Potentiometer ausgelesen und in die Werte für den Servo umgerechnet – die Variable „Greifer“ nimmt diesen Wert an. In der Klammer werden zuerst die Werte vom Sensor von 215 – 300 in den Winkel für den Servo von 30°-190° umgerechnet. (Arduino, V.1.8.9)*/
  Serial.print(" Servo Greifer: "); //Winkel des Servos an den Computer senden
  Serial.print(greifer);            /* Immer zuerst was angezeigt wird (voriger Befehl), danach die Variabel */
  pause_greifer = abs(greifer - greifer_alt) * 3;   /* Die Verzögerung für die Drehung wird ständig neu angepasst, je nachdem, wie groß die Winkeldifferenz ist. Dafür wird die differenz der alten Winkeldifferenz und der neuen genommen und mit drei multipliziert. Die neue Variable für diesen Vorgang hat immer die Vorsilbe „pause“. */
  if (pause_greifer <= 600 && greifer > 0){  /* Wenn der Winkelunterschied kleiner als 200° ist (da vorher mit drei Multipliziert wurden ist, muss man jetzt durch drei teilen, um auf diese Zahl zu kommen) und der Servowinkel nicht negativ ist, soll der Servo bewegt werden – das mache ich, damit Fehlmessungen oder falsche Werte weniger im Betrieb auffallen – eine Sicherheitsabfrage. */
  first.write(greifer); //Greifer-Servo bewegt sich zu dem vorgegebenen Winkel
  delay(pause_dreher);  //Pause für die Bewegung 
  }
  greifer_alt = greifer;    /* den aktuellen Winkel als alten Winkel nehmen, damit in der nächsten Ausführung des Codes der Wert wieder neu berechnet werden kann. */

//Hier wird jetzt in diesem Block der Dreher-Servo gesteuert, funktioniert im Grunde so wie der Obige, Variablen und Zahlen wurden aktualisiert 
  dreher = map(analogRead(accZPin), 250, 450, 30, 330);// Umrechnung der Werte
  Serial.print(" Servo Dreher: ");      //Ausgabe des Servo-Winkels an den PC
  Serial.print(dreher);             
  pause_dreher = abs(dreher - dreher_alt) * 3;  //Pause berechnen
  if (pause_dreher <= 80 && dreher > 0){    //Sicherheitsabfrage 
  second.write(dreher);				//Dreh-Servo bewegen
  delay(pause_dreher);				//Dynamische Pause
  }
  dreher_alt = dreher;				//Werte aktualisieren

/* Dieser Block funktioniert genauso wie die beiden darüber – die Variablen und Zahlen sind nur für den Neigungssensor angepasst wurden */
  neigung = map(analogRead(accYPin), 270, 410, 30, 330);
  Serial.print(" Servo Neigung: ");
  Serial.print(neigung);
  pause_neigung = abs(neigung - neigung_alt) * 5;
  if (pause_neigung <= 80 && neigung > 0){
  third.write(neigung);
  delay(pause_neigung);
  }
  neigung_alt = neigung;
}
 
